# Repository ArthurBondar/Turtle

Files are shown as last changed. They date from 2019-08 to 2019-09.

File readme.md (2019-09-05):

# Underwater Camera Project
Underwater Point of View Camera is designed for marine data collection applications. The primary goal of this project is to aid fisheries and biologist with underwater video collection.

## Features:
* 300m dept rated enclosure
* HD (1080p 30fps) video recording
* GPS location tracking
* 3-5 days battery run time ( 8hr recording per day )
* Ability to interface with various sensors

### Underwater Camera
This unit is designed to use as Point-of-view camera tag for Leatherback turtle studies. The unit features a GPS and a small power-efficient computer. The collected is stored on a microSD card.

### Line Camera
This unit is designed for stationary monitoring application used by fisheries. GPS module is optional for this system. The collected data is stored on a USB flash drive.

### Software Tools
Windows Programs for working with the unit:
* FFMPEG YAG - software for converting cameras native h264 video format to mp4
* Win32 Disk Imager - program for reading and writiing software to the unit

### System Images
Software packages are avaiable on Google Drive:
* Underwater / Line Camera Software Image: https://drive.google.com/file/d/10pP7cINGF-45ElwvxjcI6ze0uSWwasvH/view?usp=sharing

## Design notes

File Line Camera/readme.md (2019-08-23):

## Line Camera
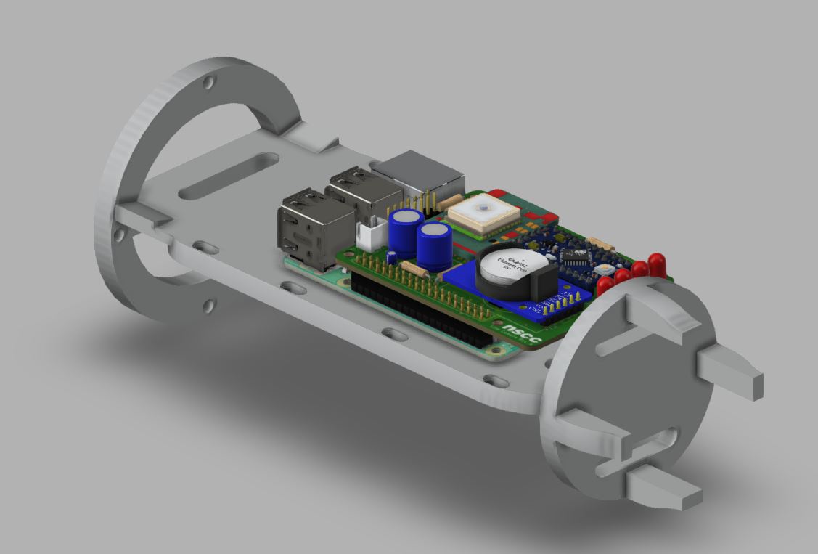
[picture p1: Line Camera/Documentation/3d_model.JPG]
cover photo


### Overview
Line Camera is designed for marine data collection. This device is used in stationary monitoring applications. Camera Tag’s video lapse characteristics can set by the user. The main interface for the system is a removable USB-flash drive. The on-board computer reads the drive during boot and stores all recorded data on it. During long deployments, more than one day, the Tag is designed to enter sleep mode to extend battery life.

### Operation
During deployment, the Tags computer records video during daytime. The main computer shuts down for night-time operation to extend battery life. Recording cycles are handled by a separate microcontroller. Video files, GPS readings, and log file are stored on a removable USB flash drive.

### Main components
* Raspberry Pi + PiCamera 1080p30
* Arduino ProMini (Atmega328)
* Battery Bank + Charger/Boost
* Custom 3D printed parts
* Custom made PCB

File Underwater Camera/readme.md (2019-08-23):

## Underwater Camera
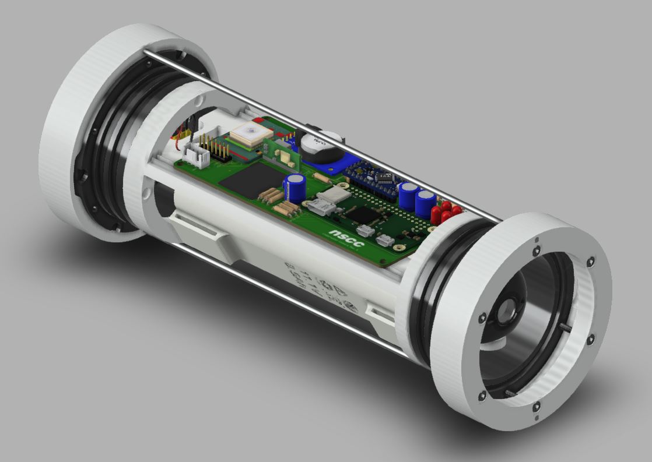
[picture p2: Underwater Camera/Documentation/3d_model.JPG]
cover photo


### Overview
Underwater Camera Tag is designed for marine data collection. This device can be used as
a POV tag for aquatic turtles. The main interface for the system is a removable USB-flash drive. The on-board computer reads the drive during boot and stores all recorded data on it. During long deployments, more than one day, the Tag is designed to enter sleep mode to extend battery life.

### Operation
During deployment, the Tags computer records video and GPS location at daytime. The main computer shuts down for night-time operation to extend battery life. Recording cycles are handled by a separate microcontroller. Video files, GPS readings, and log file are stored on a removable USB flash drive.

### Main components
* Raspberry Pi + PiCamera 1080p30
* Arduino ProMini (Atmega328)
* Battery Bank + Charger/Boost
* Custom 3D printed parts
* Custom made PCB

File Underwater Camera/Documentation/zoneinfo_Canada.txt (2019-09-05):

Atlantic
Central
Eastern
Mountain
Newfoundland
Pacific
Saskatchewan
Yukon

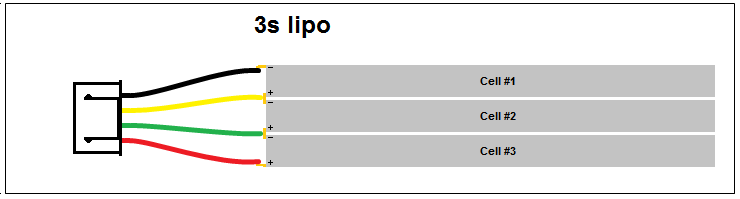
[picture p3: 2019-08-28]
Underwater Camera/Documentation/diagram-3s_lipo.png

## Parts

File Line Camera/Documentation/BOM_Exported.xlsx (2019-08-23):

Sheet: By Part
Qty | Value | Device | Parts | Description
1 | 0.1uF | CAP_THCAP-TH-2MM | C1 | Capacitor Electro. TH
1 | 10k | RES_THRES-D8.5 | R2 | Resistor TH
1 | 30k | RES_THRES-D8.5 | R1 | Resistor TH
4 | 330 | RES_THRES-D8.5 | R3, R4, R5, R6 | Resistor TH
2 | 47uF | CAP_THCAP-ELECTRO-5.08 | C2, C3 | Capacitor Electro. TH
1 | ADA_GPS | ADA_ULTIMATE_GPS9P_BREAKOUT | U3 | Ultimate GPS from Adafruit - Breakout
1 | DS3231_MODULE | DS3231_MODULE | IC1 | DS3231 RTC Breakout Module
1 | HDR2X7 | HDR2X7HDR2X7 | J2
1 | JST-2P | HDR1X22P2.54MM | J1 | Header 2pin 2.54mm pitch
4 | LED_THLED-2.54 | LED_THLED-2.54 | D1, D2, D3, D4 | TH LED - large
1 | PRO_MINI | PRO_MINI | U1 | Arduino Pro Mini from SparkFun 3.3V
1 | RPIPI_3B+ | RPIPI_3B+ | U2 | Pi Header with different package variations

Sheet: By Ref. Des.
Ref. Des. | Value | Device | Description
C1 | 0.1uF | CAP_THCAP-TH-2MM | Capacitor Electro. TH
C2 | 47uF | CAP_THCAP-ELECTRO-5.08 | Capacitor Electro. TH
C3 | 47uF | CAP_THCAP-ELECTRO-5.08 | Capacitor Electro. TH
D1 | LED_THLED-2.54 | LED_THLED-2.54 | TH LED - large
D2 | LED_THLED-2.54 | LED_THLED-2.54 | TH LED - large
D3 | LED_THLED-2.54 | LED_THLED-2.54 | TH LED - large
D4 | LED_THLED-2.54 | LED_THLED-2.54 | TH LED - large
IC1 | DS3231_MODULE | DS3231_MODULE | DS3231 RTC Breakout Module
J1 | JST-2P | HDR1X22P2.54MM | Header 2pin 2.54mm pitch
J2 | HDR2X7 | HDR2X7HDR2X7
R1 | 30k | RES_THRES-D8.5 | Resistor TH
R2 | 10k | RES_THRES-D8.5 | Resistor TH
R3 | 330 | RES_THRES-D8.5 | Resistor TH
R4 | 330 | RES_THRES-D8.5 | Resistor TH
R5 | 330 | RES_THRES-D8.5 | Resistor TH
R6 | 330 | RES_THRES-D8.5 | Resistor TH
U1 | PRO_MINI | PRO_MINI | Arduino Pro Mini from SparkFun 3.3V
U2 | RPIPI_3B+ | RPIPI_3B+ | Pi Header with different package variations
U3 | ADA_GPS | ADA_ULTIMATE_GPS9P_BREAKOUT | Ultimate GPS from Adafruit - Breakout

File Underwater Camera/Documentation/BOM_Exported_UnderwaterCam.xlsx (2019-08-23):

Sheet: By Part
Qty | Value | Device | Parts | Description
2 | 0.1uF | CAP_THCAP-TH-2MM | C1, C5 | Capacitor Electro. TH
1 | 1.35k | RES_THRES-D8.5 | R3 | Resistor TH
1 | 10k | RES_THRES-D8.5 | R2 | Resistor TH
1 | 30k | RES_THRES-D8.5 | R1 | Resistor TH
6 | 33 | RES_THRES-D8.5 | R8, R9, R10, R11, R12, R13 | Resistor TH
4 | 330 | RES_THRES-D8.5 | R4, R5, R6, R7 | Resistor TH
3 | 47uF | CAP_THCAP-ELECTRO-5.08 | C2, C3, C4 | Capacitor Electro. TH
1 | ADA_GPS | ADA_ULTIMATE_GPS9P_BREAKOUT | U3 | Ultimate GPS from Adafruit - Breakout
1 | DS3231_MODULE | DS3231_MODULE | IC1 | DS3231 RTC Breakout Module
1 | HDR2X7 | HDR2X7HDR2X7 | J2
1 | JST-XH | HDR1X4JST-XH | J1 | HEADER 1x4
4 | LED_THLED-2.54 | LED_THLED-2.54 | D1, D2, D3, D4 | TH LED - large
1 | MICRO_SD | MICRO_SD_SNIFFER | IC3 | SparkFun microSD sniffer - breaks out SDIO interface
1 | MICRO_SD_1BIT | MICRO_SD | IC4 | Sparkfun microSD Breakout - SPI/SDIO 1bit accessible
1 | OKX-T/5-D123 | OKX-T/5-D123DMODEL | IC2 | OKX-T/5-D12 by Murata Inc. - Monolithic DC/DC Converter
1 | PI_ZERO | PI_ZERO | U2 | Pi Zero W
1 | PRO_MINI | PRO_MINI | U1 | Arduino Pro Mini from SparkFun 3.3V

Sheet: By Ref. Des.
Ref. Des. | Value | Device | Description
C1 | 0.1uF | CAP_THCAP-TH-2MM | Capacitor Electro. TH
C2 | 47uF | CAP_THCAP-ELECTRO-5.08 | Capacitor Electro. TH
C3 | 47uF | CAP_THCAP-ELECTRO-5.08 | Capacitor Electro. TH
C4 | 47uF | CAP_THCAP-ELECTRO-5.08 | Capacitor Electro. TH
C5 | 0.1uF | CAP_THCAP-TH-2MM | Capacitor Electro. TH
D1 | LED_THLED-2.54 | LED_THLED-2.54 | TH LED - large
D2 | LED_THLED-2.54 | LED_THLED-2.54 | TH LED - large
D3 | LED_THLED-2.54 | LED_THLED-2.54 | TH LED - large
D4 | LED_THLED-2.54 | LED_THLED-2.54 | TH LED - large
IC1 | DS3231_MODULE | DS3231_MODULE | DS3231 RTC Breakout Module
IC2 | OKX-T/5-D123 | OKX-T/5-D123DMODEL | OKX-T/5-D12 by Murata Inc. - Monolithic DC/DC Converter
IC3 | MICRO_SD | MICRO_SD_SNIFFER | SparkFun microSD sniffer - breaks out SDIO interface
IC4 | MICRO_SD_1BIT | MICRO_SD | Sparkfun microSD Breakout - SPI/SDIO 1bit accessible
J1 | JST-XH | HDR1X4JST-XH | HEADER 1x4
J2 | HDR2X7 | HDR2X7HDR2X7
R1 | 30k | RES_THRES-D8.5 | Resistor TH
R2 | 10k | RES_THRES-D8.5 | Resistor TH
R3 | 1.35k | RES_THRES-D8.5 | Resistor TH
R4 | 330 | RES_THRES-D8.5 | Resistor TH
R5 | 330 | RES_THRES-D8.5 | Resistor TH
R6 | 330 | RES_THRES-D8.5 | Resistor TH
R7 | 330 | RES_THRES-D8.5 | Resistor TH
R8 | 33 | RES_THRES-D8.5 | Resistor TH
R9 | 33 | RES_THRES-D8.5 | Resistor TH
R10 | 33 | RES_THRES-D8.5 | Resistor TH
R11 | 33 | RES_THRES-D8.5 | Resistor TH
R12 | 33 | RES_THRES-D8.5 | Resistor TH
R13 | 33 | RES_THRES-D8.5 | Resistor TH
U1 | PRO_MINI | PRO_MINI | Arduino Pro Mini from SparkFun 3.3V
U2 | PI_ZERO | PI_ZERO | Pi Zero W
U3 | ADA_GPS | ADA_ULTIMATE_GPS9P_BREAKOUT | Ultimate GPS from Adafruit - Breakout

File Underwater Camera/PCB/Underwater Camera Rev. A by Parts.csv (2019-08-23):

Part | Value | Device | Package | Description
C1 | 0.1uF | CAP_THCAP-TH-2MM | CAPPRD254W65D300H300B | Capacitor Electro. TH
C2 | 47uF | CAP_THCAP-ELECTRO-5.08 | CAPPRD508W65D1000H1100B | Capacitor Electro. TH
C3 | 47uF | CAP_THCAP-ELECTRO-5.08 | CAPPRD508W65D1000H1100B | Capacitor Electro. TH
C4 | 47uF | CAP_THCAP-ELECTRO-5.08 | CAPPRD508W65D1000H1100B | Capacitor Electro. TH
C5 | 0.1uF | CAP_THCAP-TH-2MM | CAPPRD254W65D300H300B | Capacitor Electro. TH
D1 | LED_THLED-2.54 | LED_THLED-2.54 | LEDRD254W60D565H860B | TH LED - large
D2 | LED_THLED-2.54 | LED_THLED-2.54 | LEDRD254W60D565H860B | TH LED - large
D3 | LED_THLED-2.54 | LED_THLED-2.54 | LEDRD254W60D565H860B | TH LED - large
D4 | LED_THLED-2.54 | LED_THLED-2.54 | LEDRD254W60D565H860B | TH LED - large
IC1 | DS3231_MODULE | DS3231_MODULE | DS3231_MODULE | DS3231 RTC Breakout Module
IC2 | OKX-T/5-D123 | OKX-T/5-D123DMODEL | OKX-T/5-D12 | OKX-T/5-D12 by Murata Inc. - Monolithic DC/DC Converter
IC3 | MICRO_SD | MICRO_SD_SNIFFER | MICRO_SD_SDIO | SparkFun microSD sniffer - breaks out SDIO interface
IC4 | MICRO_SD_1BIT | MICRO_SD | MICRO_SD_SDIO1B | Sparkfun microSD Breakout - SPI/SDIO 1bit accessible
J1 | JST-XH | HDR1X4JST-XH | HDR1X4 | HEADER 1x4
J2 | HDR2X7 | HDR2X7HDR2X7 | HDR2X7
R1 | 30k | RES_THRES-D8.5 | RESAD1176W63L850D250B | Resistor TH
R2 | 10k | RES_THRES-D8.5 | RESAD1176W63L850D250B | Resistor TH
R3 | 1.35k | RES_THRES-D8.5 | RESAD1176W63L850D250B | Resistor TH
R4 | 330 | RES_THRES-D8.5 | RESAD1176W63L850D250B | Resistor TH
R5 | 330 | RES_THRES-D8.5 | RESAD1176W63L850D250B | Resistor TH
R6 | 330 | RES_THRES-D8.5 | RESAD1176W63L850D250B | Resistor TH
R7 | 330 | RES_THRES-D8.5 | RESAD1176W63L850D250B | Resistor TH
R8 | 33 | RES_THRES-D8.5 | RESAD1176W63L850D250B | Resistor TH
R9 | 33 | RES_THRES-D8.5 | RESAD1176W63L850D250B | Resistor TH
R10 | 33 | RES_THRES-D8.5 | RESAD1176W63L850D250B | Resistor TH
R11 | 33 | RES_THRES-D8.5 | RESAD1176W63L850D250B | Resistor TH
R12 | 33 | RES_THRES-D8.5 | RESAD1176W63L850D250B | Resistor TH
R13 | 33 | RES_THRES-D8.5 | RESAD1176W63L850D250B | Resistor TH
U1 | PRO_MINI | PRO_MINI | PRO_MINI | Arduino Pro Mini from SparkFun 3.3V
U2 | PI_ZERO | PI_ZERO | PI_ZERO_W | Pi Zero W
U3 | ADA_GPS | ADA_ULTIMATE_GPS9P_BREAKOUT | ADA_ULTIMATE_GPS | Ultimate GPS from Adafruit - Breakout

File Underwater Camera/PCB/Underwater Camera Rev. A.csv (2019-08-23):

Qty | Value | Device | Package | Parts | Description
2 | 0.1uF | CAP_THCAP-TH-2MM | CAPPRD254W65D300H300B | C1, C5 | Capacitor Electro. TH
1 | 1.35k | RES_THRES-D8.5 | RESAD1176W63L850D250B | R3 | Resistor TH
1 | 10k | RES_THRES-D8.5 | RESAD1176W63L850D250B | R2 | Resistor TH
1 | 30k | RES_THRES-D8.5 | RESAD1176W63L850D250B | R1 | Resistor TH
6 | 33 | RES_THRES-D8.5 | RESAD1176W63L850D250B | R8, R9, R10, R11, R12, R13 | Resistor TH
4 | 330 | RES_THRES-D8.5 | RESAD1176W63L850D250B | R4, R5, R6, R7 | Resistor TH
3 | 47uF | CAP_THCAP-ELECTRO-5.08 | CAPPRD508W65D1000H1100B | C2, C3, C4 | Capacitor Electro. TH
1 | ADA_GPS | ADA_ULTIMATE_GPS9P_BREAKOUT | ADA_ULTIMATE_GPS | U3 | Ultimate GPS from Adafruit - Breakout
1 | DS3231_MODULE | DS3231_MODULE | DS3231_MODULE | IC1 | DS3231 RTC Breakout Module
1 | HDR2X7 | HDR2X7HDR2X7 | HDR2X7 | J2
1 | JST-XH | HDR1X4JST-XH | HDR1X4 | J1 | HEADER 1x4
4 | LED_THLED-2.54 | LED_THLED-2.54 | LEDRD254W60D565H860B | D1, D2, D3, D4 | TH LED - large
1 | MICRO_SD | MICRO_SD_SNIFFER | MICRO_SD_SDIO | IC3 | SparkFun microSD sniffer - breaks out SDIO interface
1 | MICRO_SD_1BIT | MICRO_SD | MICRO_SD_SDIO1B | IC4 | Sparkfun microSD Breakout - SPI/SDIO 1bit accessible
1 | OKX-T/5-D123 | OKX-T/5-D123DMODEL | OKX-T/5-D12 | IC2 | OKX-T/5-D12 by Murata Inc. - Monolithic DC/DC Converter
1 | PI_ZERO | PI_ZERO | PI_ZERO_W | U2 | Pi Zero W
1 | PRO_MINI | PRO_MINI | PRO_MINI | U1 | Arduino Pro Mini from SparkFun 3.3V

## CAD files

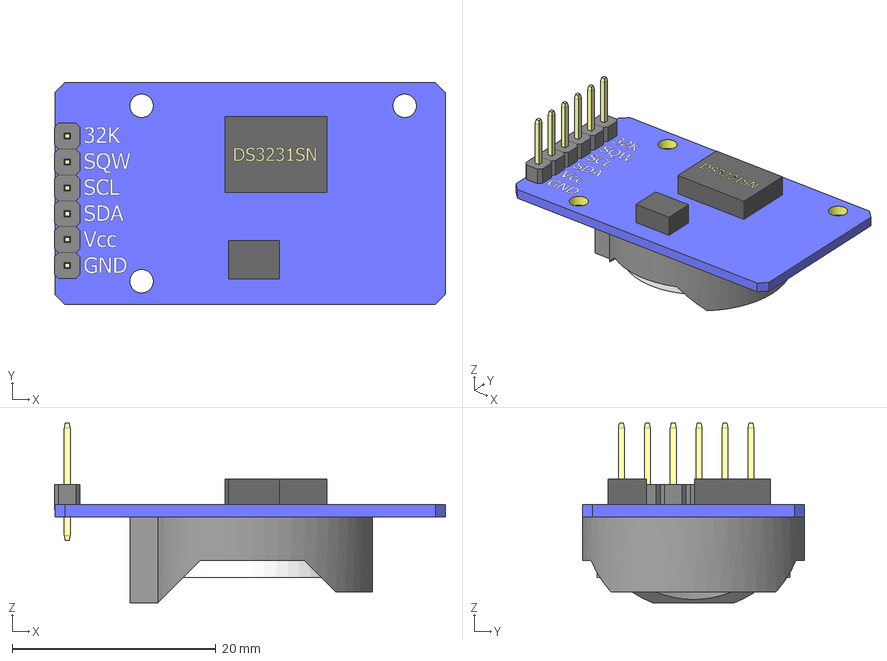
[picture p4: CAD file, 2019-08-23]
Line Camera/PCB/3D Models/DS3231 Timer Assembly.stp
38.3 x 21.8 x 17.6 mm

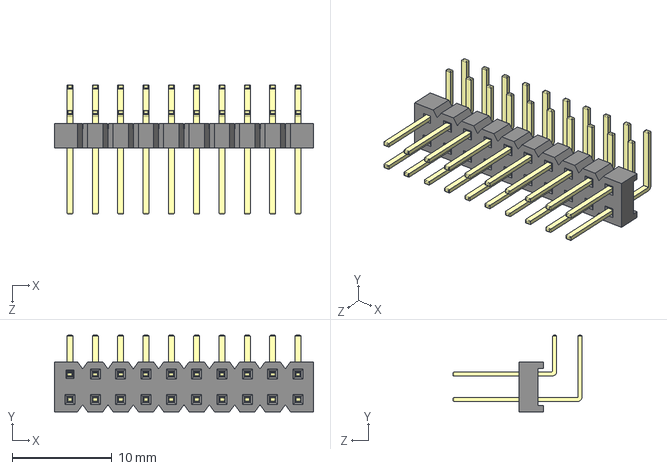
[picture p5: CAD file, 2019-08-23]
Line Camera/PCB/3D Models/20 pin connector_part2.STEP
26.0 x 7.67 x 12.9 mm

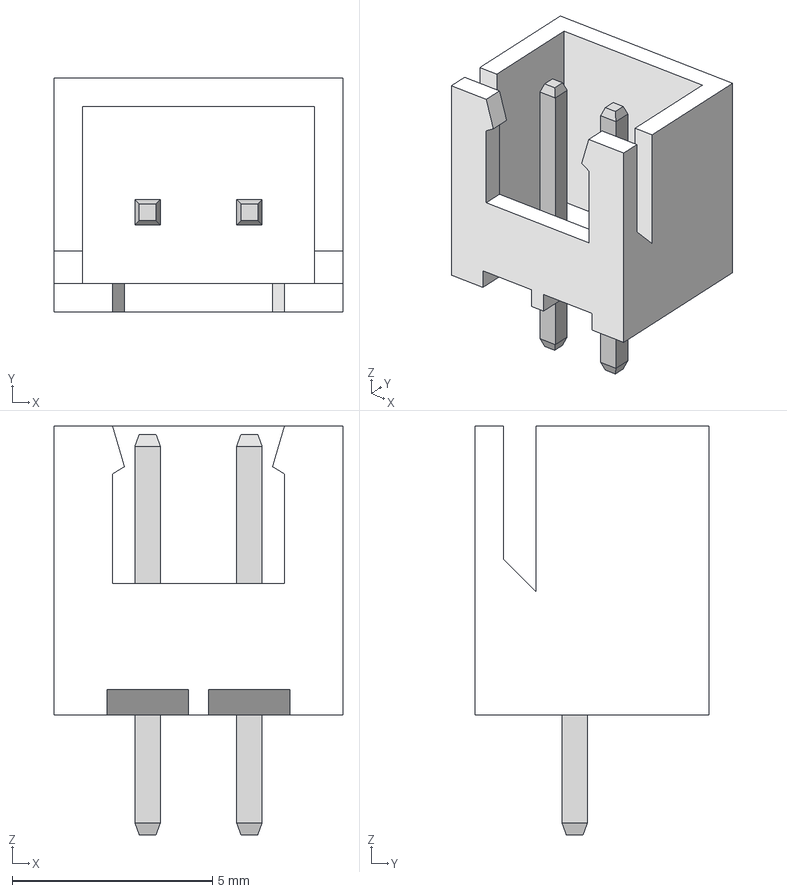
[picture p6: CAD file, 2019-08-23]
Underwater Camera/PCB/3D Models/JST - XH - Thru (V) - 2Pin - 2.54mm.stp
7.21 x 5.84 x 10.2 mm

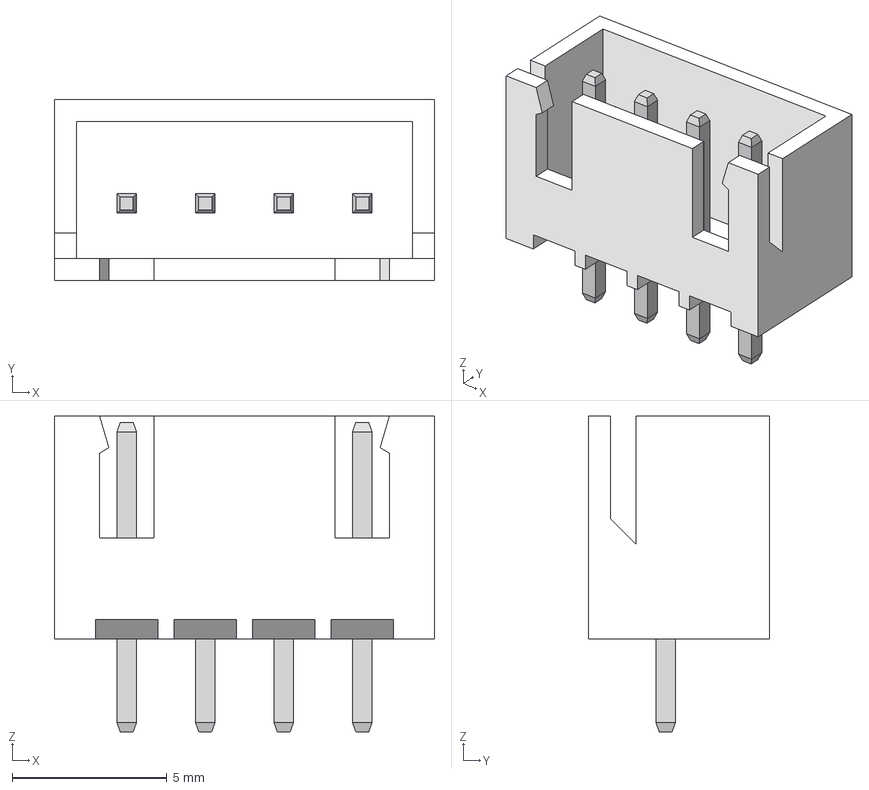
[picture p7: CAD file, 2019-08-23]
Underwater Camera/PCB/3D Models/JST - XH - Thru (V) - 4Pin - 2.54mm.stp
12.3 x 5.84 x 10.2 mm

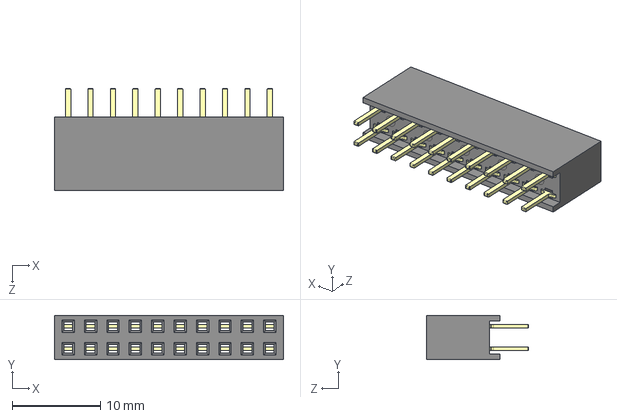
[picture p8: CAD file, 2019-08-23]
Line Camera/PCB/3D Models/20 pin connector.STEP
26.0 x 5.00 x 11.6 mm

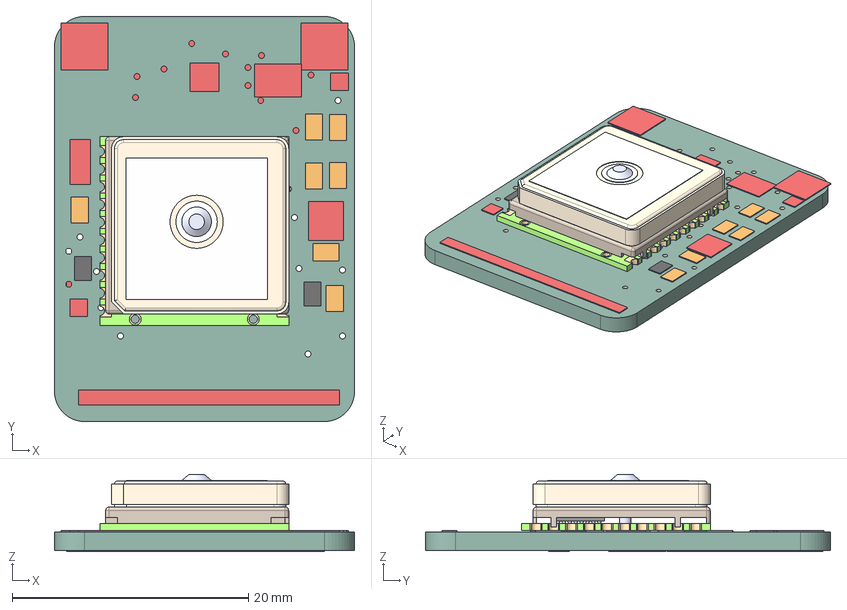
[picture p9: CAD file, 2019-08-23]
Underwater Camera/PCB/3D Models/Adafruit Ultimate GPS.stp
25.4 x 34.3 x 6.52 mm
Board
SOT23-5
CHIPLED_0805
0805-NO x 7
MOUNTINGHOLE_2 x 2
SOD-323 x 2
CR1220
FIDUCIAL_1MM x 2
ADAFRUIT_2
U
1X09_ROUND_70
PCBFEAT-REV-040
ADAFRUIT_5MM
PCB
VFBGA-64
RF Shield
Adhesive Pad
Ceramic Antenna
Rivet

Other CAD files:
Underwater Camera/PCB/3D Models/SparkFun_MicroSD_Sniffer.step
Line Camera/PCB/3D Models/SparkFun_MicroSD_Sniffer.step
Line Camera/PCB/3D Models/SparkFun_MicroSD_Sniffer.blend
Line Camera/PCB/3D Models/SparkFun_MicroSD_Sniffer.stl
Underwater Camera/PCB/3D Models/SparkFun_MicroSD_Sniffer.blend
Underwater Camera/PCB/3D Models/SparkFun_MicroSD_Sniffer.stl

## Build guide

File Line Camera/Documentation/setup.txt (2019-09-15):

# This file is used to set up system configuration
# Edit fields after the equals sign
# Use comments, marked (#), for reference

# Number of recording days left since start of the program
# Use this parameter to limit the number of recording cycles
# If unused, set to a high number > 5
days = 3

# Duration of each video in minutes (default 30)
sections = 30

# Time for the device to turn on in 24hr format [hh:mm]
start = 22:00

# Time for the device to turn off in 24hr format [hh:mm]
end = 06:00

# New datetime and timezone parameers 
# Note: should only be set once after coin cell battery replacement
# Set new system date and time (yes/no)
set date-time = no
# New datetime, format: DD-MM-YYYY T HH:MM:SS
new date-time = 2019-09-09 T 19:06:00
# Set new system timezone (yes/no)
set timezone = no
# Reference - https://en.wikipedia.org/wiki/List_of_tz_database_time_zones
new timezone = America/New_York

# Video recording mode
#	Mode	Resolution	Ratio	FPS		FOV
#	1	1920x1080	16:9	0.1-30fps	Partial
#	2	3280x2464	4:3	0.1-15fps	FulL	(not for video)
#	3	3280x2464	4:3	0.1-15fps	Full	(not for video)
#	4	1640x1232	4:3	0.1-40fps	Full
#	5	1640x922	16:9	0.1-40fps	Full
#	6	1280x720	16:9	40-90fps	Partial
#	7	640x480		4:3	40-90fps	Partial
video mode = 4

# Frames per second (default 25)
# Refer to the table above for acceptible frame rates
# higher rates result in larger fies
fps = 30

# Rotation of the camera module (Default 180) 
# between 0 and 359
rotation = 180

# Enable the use of the GPS module (yes/no)
gps enable = no
# Interval for GPS capture in seconds (Default 50s)
gps interval = 60

# Maximum Video Bitrate in Mbit/sec (Default=10)
# Higher bitrate produce higher quality videos
# Very high rates result in load on the CPU (power consumption)
# and large video files stored on the storage device
#	Bit rate (Mps)	Description			Write Speed	Video Size per Hr
#	25		highest quality, larger files	3.12 MB/s	11.3 GB
#	15		very high quality		1.87 MB/s	6.73 GB
#	10		good quality			1.25 MB/s	4.50 GB
#	5		medium quality (small files)	0.62 MB/s	2.23 GB
bitrate = 10

# Interval for logging processor data to the disk (in minutes)
log interval = 10

# Specify the printed circuit board version ( line camera / underwater camera )
board version = line camera

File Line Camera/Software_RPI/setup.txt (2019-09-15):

# This file is used to set up system configuration
# Edit fields after the equals sign
# Use comments, marked (#), for reference

# Number of recording days left since start of the program
# Use this parameter to limit the number of recording cycles
# If unused, set to a high number > 5
days = 2

# Duration of each video section in minutes (default 30)
sections = 30

# Time for the device to turn on in 24hr format [hh:mm]
start = 08:00

# Time for the device to turn off in 24hr format [hh:mm]
end = 22:00

# New datetime and timezone parameers 
# Note: should only be set once after coin cell battery replacement
# Set new system date and time (yes/no)
# New datetime, format: DD-MM-YYYY T HH:MM:SS
set date-time = no
new date-time = 2019-09-14 T 20:30:00

# Set new system timezone (yes/no)
# Reference - https://en.wikipedia.org/wiki/List_of_tz_database_time_zones
# use America/New_York for USA, MA
set timezone = no
new timezone = America/Halifax

# Video recording mode
#	Mode	Resolution	Ratio	FPS		FOV
#	1	1920x1080	16:9	0.1-30fps	Partial
#	2	3280x2464	4:3	0.1-15fps	FulL	(not for video)
#	3	3280x2464	4:3	0.1-15fps	Full	(not for video)
#	4	1640x1232	4:3	0.1-40fps	Full
#	5	1640x922	16:9	0.1-40fps	Full
#	6	1280x720	16:9	40-90fps	Partial
#	7	640x480		4:3	40-90fps	Partial
video mode = 4

# Frames per second (default 25)
# Refer to the table above for acceptible frame rates
# higher rates result in larger fies
fps = 30

# Rotation of the camera module (Default 180) 
# between 0 and 359
rotation = 0

# Enable the use of the GPS module (yes/no)
gps enable = yes
# Interval for GPS capture in seconds (Default 50s)
gps interval = 60

# Maximum Video Bitrate in Mbit/sec (Default=10)
# Higher bitrate produce higher quality videos
# Very high rates result in load on the CPU (power consumption)
# and large video files stored on the storage device
#	Bit rate (Mps)	Description			Write Speed	Video Size per Hr
#	25		highest quality, larger files	3.12 MB/s	11.3 GB
#	15		very high quality		1.87 MB/s	6.73 GB
#	10		good quality			1.25 MB/s	4.50 GB
#	5		medium quality (small files)	0.62 MB/s	2.23 GB
bitrate = 10

# Interval for logging processor data to the disk (in minutes)
log interval = 15

# Specify the printed circuit board version ( line camera / underwater camera )
board version = underwater camera

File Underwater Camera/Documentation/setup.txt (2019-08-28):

# This file is used to set up system configuration
# Edit fields after the equals sign
# Use comments (#) for reference

# Number of recording days left since start of the program
# Use this parameter to limit the number of recording cycles
# If unused, set to a high number > 5
days = 4

# Duration of each video in minutes (default 30)
sections = 20

# Time for the device to turn on in 24hr format [hh:mm]
start = 15:00

# Time for the device to turn off in 24hr format [hh:mm]
end = 16:30

# New datetime and timezone parameers - should only be set once after coin cell battery replacement
# Set new system date and time (yes/no)
set date-time = no
# New datetime, format - DD-MM-YYYY_HH:MM:SS
new date-time = 18-08-2019_18:45:10
# Set new system timezone (yes/no)
set timezone = no
# Reference - https://en.wikipedia.org/wiki/List_of_tz_database_time_zones
new timezone = America/Halifax

# Video recording mode
#	Mode	Resolution	Ratio	FPS		FOV
#	1	1920x1080	16:9	0.1-30fps	Partial
#	2	3280x2464	4:3	0.1-15fps	FulL	(not for video)
#	3	3280x2464	4:3	0.1-15fps	Full	(not for video)
#	4	1640x1232	4:3	0.1-40fps	Full
#	5	1640x922	16:9	0.1-40fps	Full
#	6	1280x720	16:9	40-90fps	Partial
#	7	640x480		4:3	40-90fps	Partial
video mode = 5

# Frames per second (default 25)
# Refer to the table above for acceptible frame rates
# higher rates result in larger fies
fps = 25

# Rotation of the camera module (Default 180) 
# between 0 and 359
rotation = 180

# Enable the use of the GPS module ( yes / no )
gps enable = no
# Interval for GPS capture in seconds (Default 50s)
gps interval = 60

# Maximum Video Bitrate in Mbit/sec (Default=10)
# Higher bitrate produce higher quality videos
# Very high rates result in load on the CPU (power consumption)
# and large video files stored on the storage device
#	Bit rate (Mps)	Description			Write Speed	Video Size per Hr
#	25		highest quality, larger files	3.12 MB/s	11.3 GB
#	15		very high quality		1.87 MB/s	6.73 GB
#	10		good quality			1.25 MB/s	4.50 GB
#	5		medium quality (small files)	0.62 MB/s	2.23 GB
bitrate = 10

# Interval for logging processor data to the disk (in minutes)
log interval = 5

# Specify the printed circuit board version ( line camera / underwater camera )
board version = line camera

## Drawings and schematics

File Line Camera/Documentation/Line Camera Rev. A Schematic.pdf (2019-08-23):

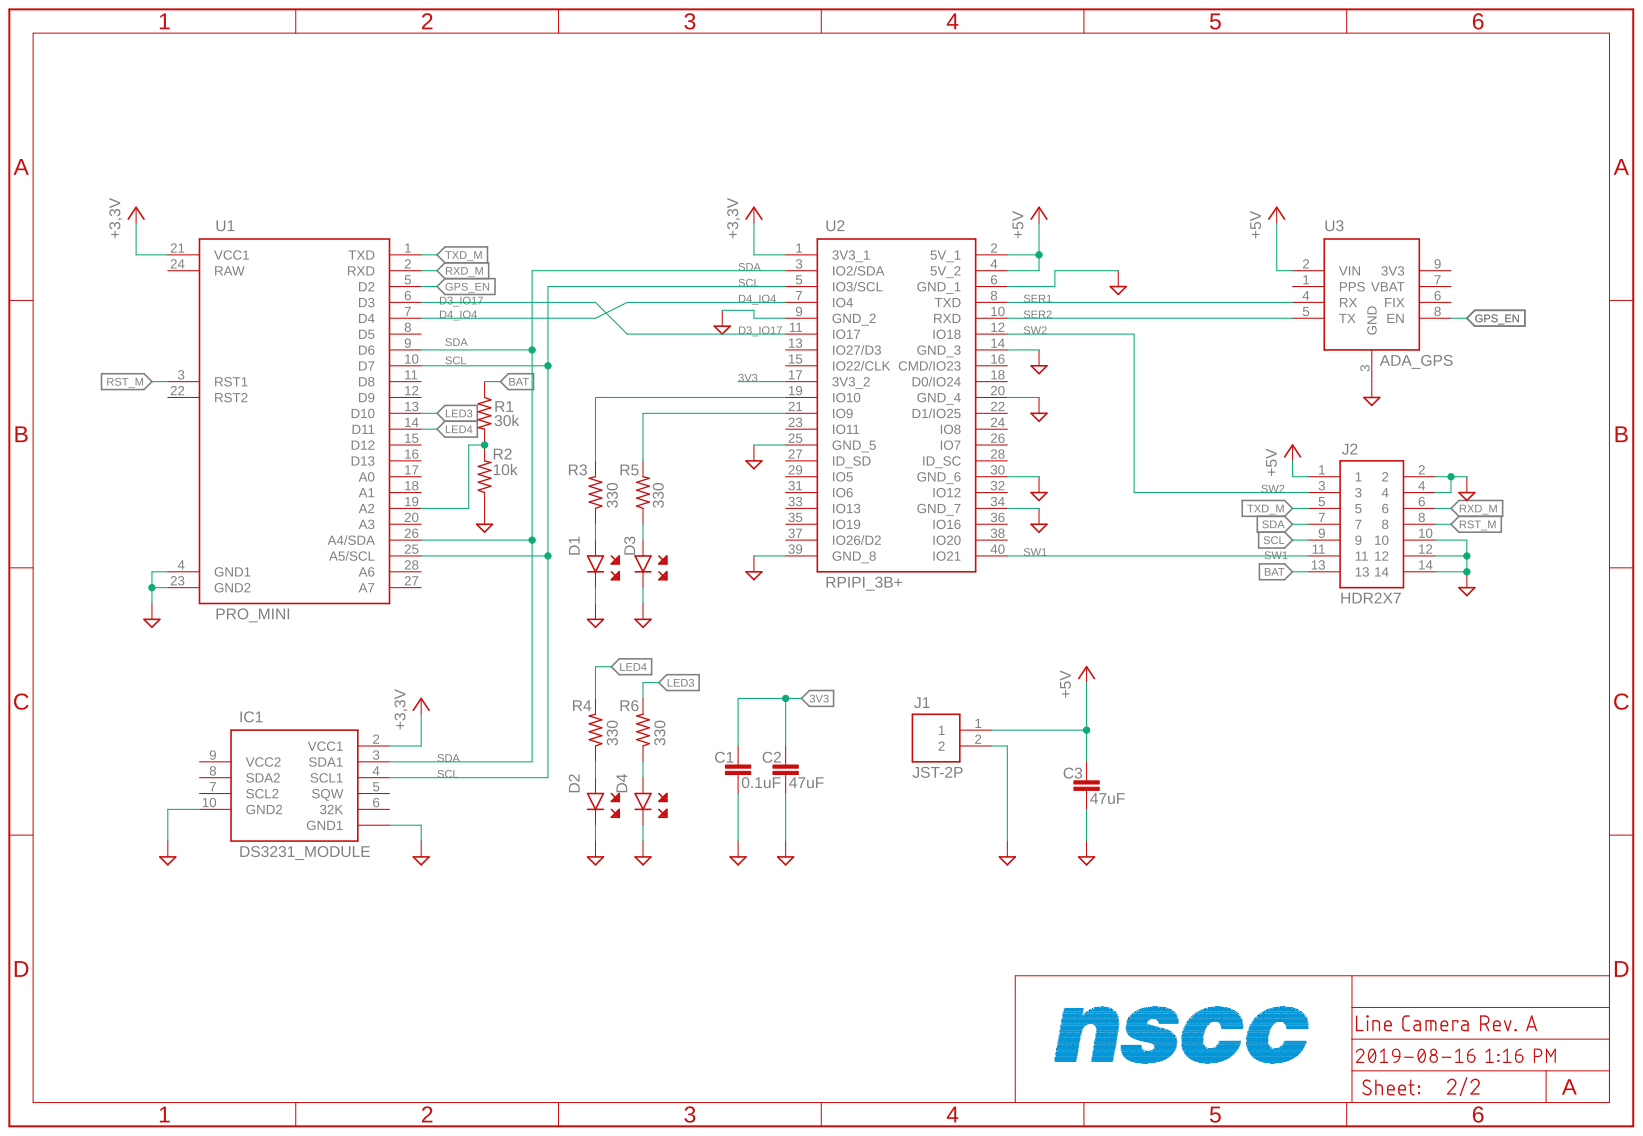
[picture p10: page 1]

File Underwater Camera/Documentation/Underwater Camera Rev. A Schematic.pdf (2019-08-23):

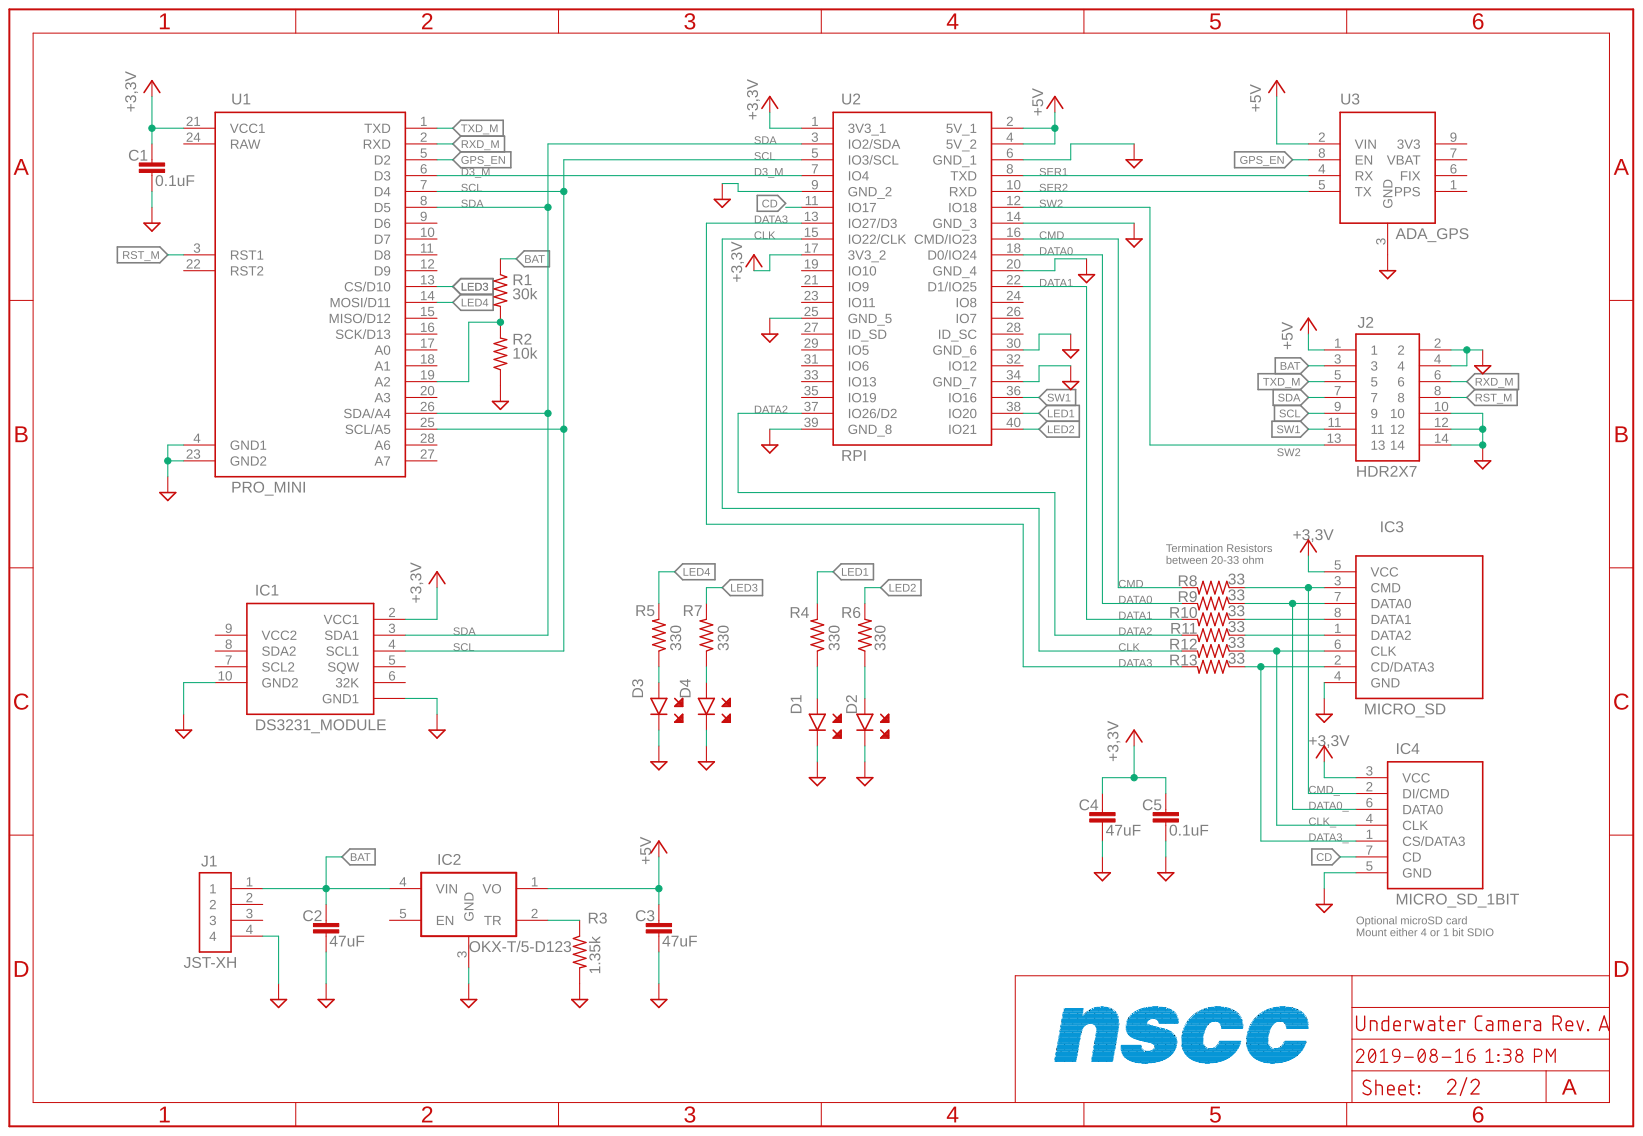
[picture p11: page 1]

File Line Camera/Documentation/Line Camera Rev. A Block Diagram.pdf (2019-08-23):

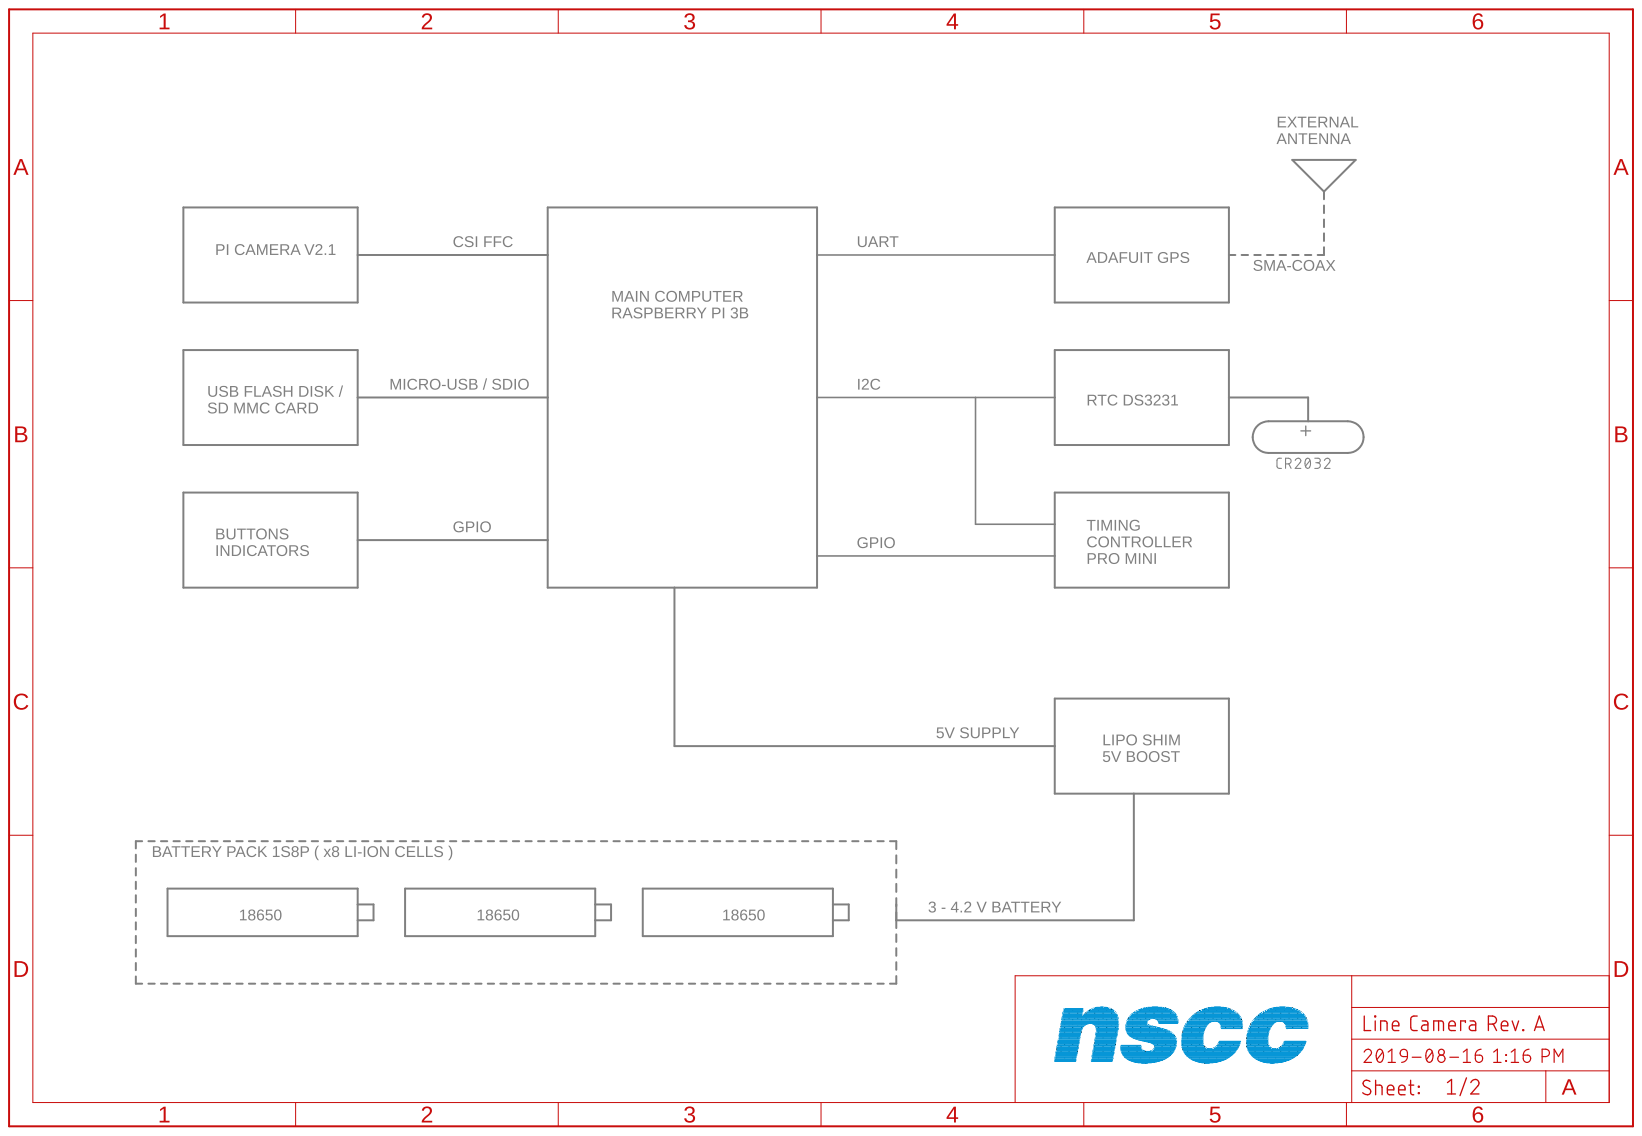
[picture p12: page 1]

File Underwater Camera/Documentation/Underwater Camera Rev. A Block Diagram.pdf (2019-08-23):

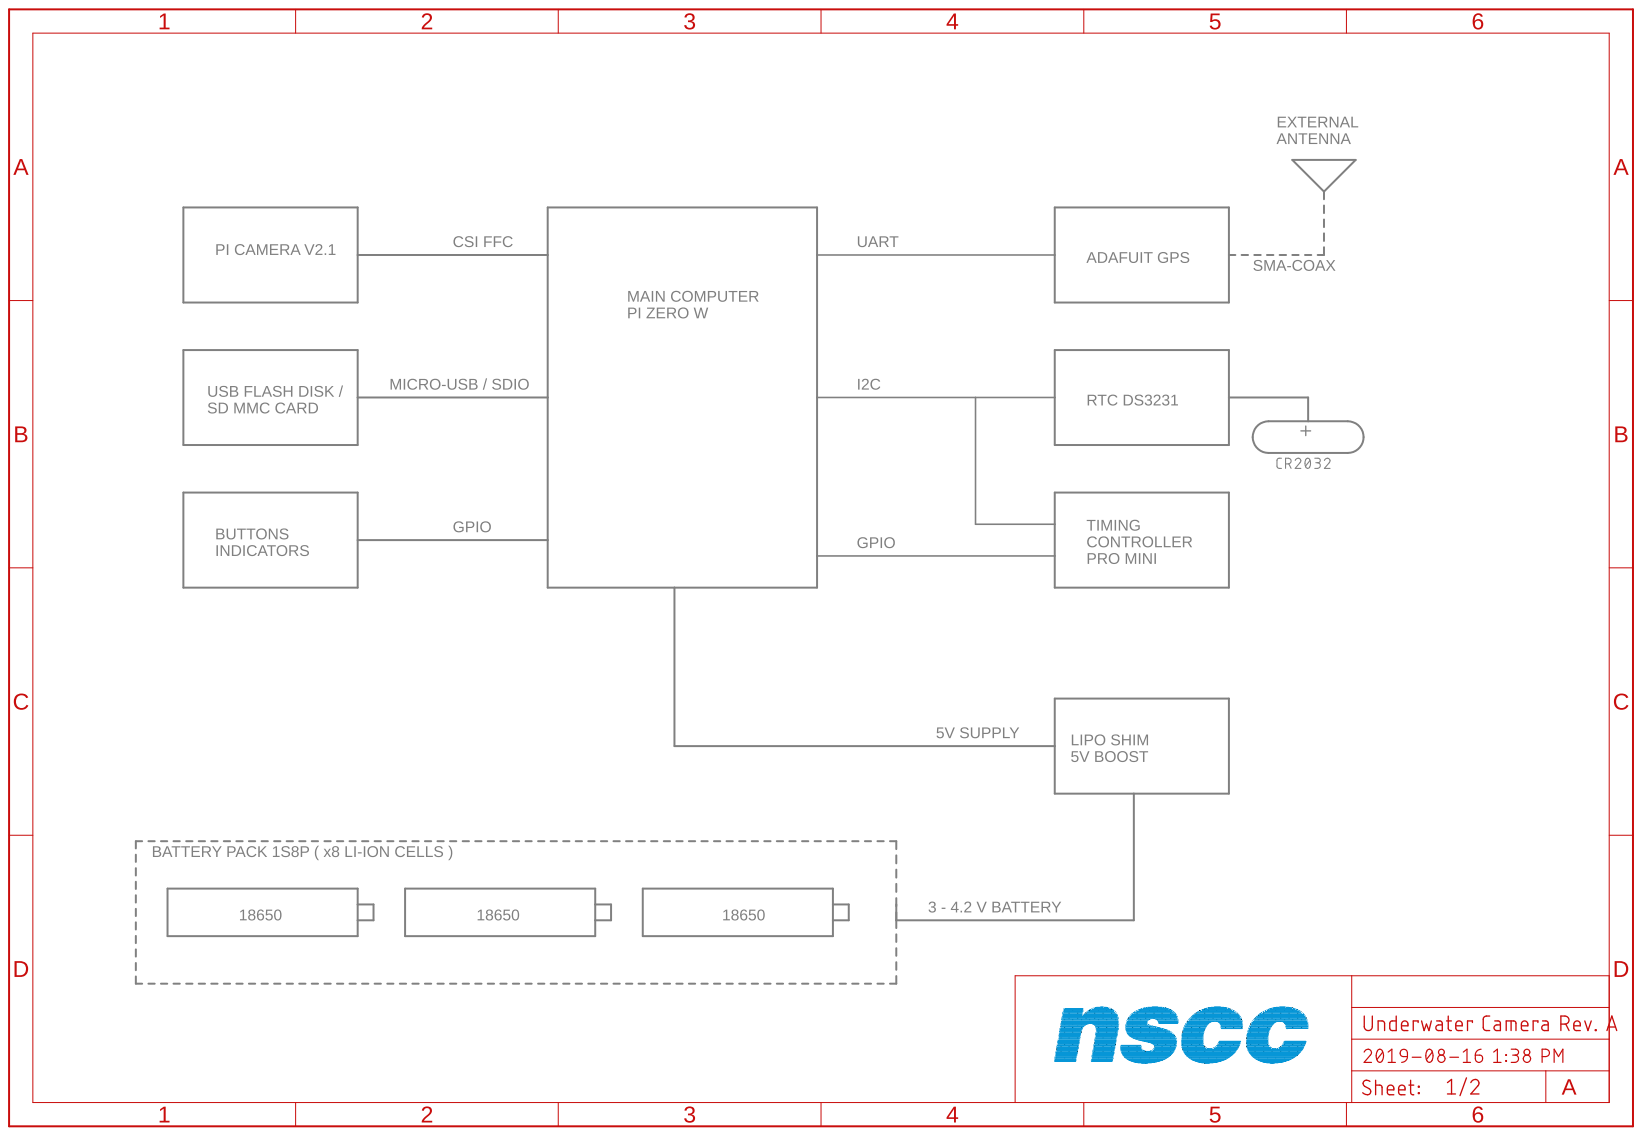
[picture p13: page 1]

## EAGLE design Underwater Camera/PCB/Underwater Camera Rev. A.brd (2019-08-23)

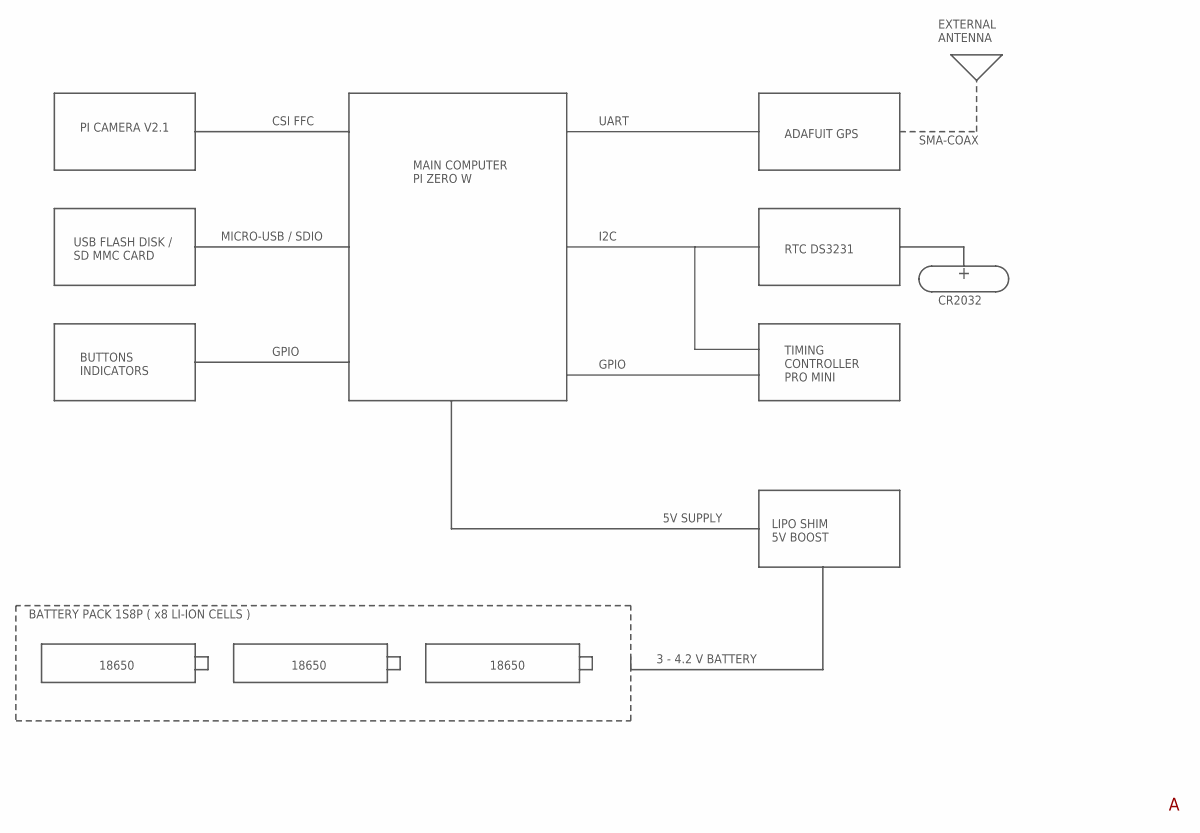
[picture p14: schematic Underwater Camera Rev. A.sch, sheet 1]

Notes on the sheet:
BATTERY PACK 1S8P ( x8 LI-ION CELLS )
LIPO SHIM 5V BOOST
MAIN COMPUTER PI ZERO W
TIMING CONTROLLER PRO MINI
PI CAMERA V2.1
USB FLASH DISK / SD MMC CARD
BUTTONS INDICATORS
ADAFUIT GPS
RTC DS3231
GPIO
5V SUPPLY
3 - 4.2 V BATTERY
SMA-COAX
EXTERNAL ANTENNA
18650
CR2032
MICRO-USB / SDIO
CSI FFC
I2C
UART

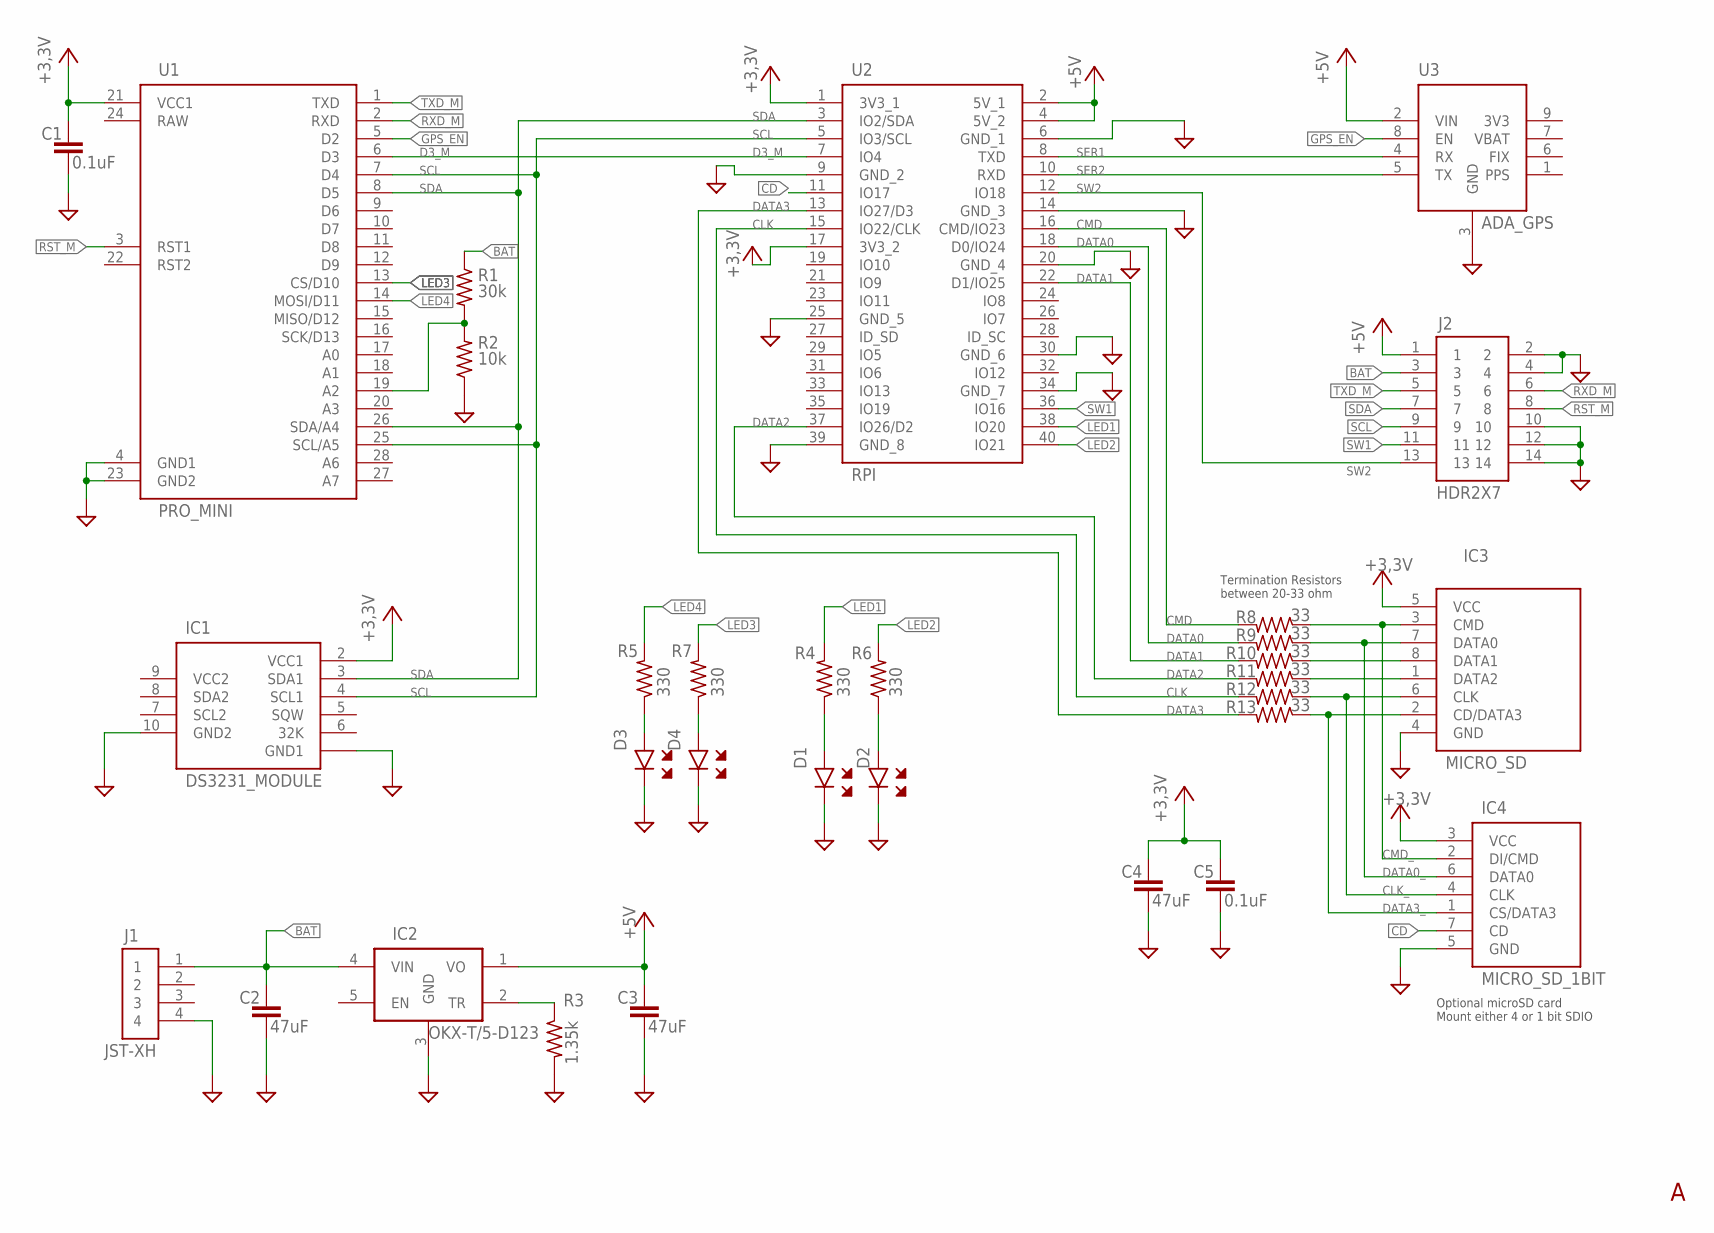
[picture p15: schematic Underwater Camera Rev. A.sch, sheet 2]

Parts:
C1, C5: 0.1uF; CAPPRD254W65D300H300B
C2, C3, C4: 47uF; CAPPRD508W65D1000H1100B
D1, D2, D3, D4: LED_THLED-2.54; LEDRD254W60D565H860B
IC1: DS3231_MODULE
IC2: OKX-T/5-D123; OKX-T/5-D12
IC3: MICRO_SD; MICRO_SD_SDIO
IC4: MICRO_SD_1BIT; MICRO_SD_SDIO1B
J1: JST-XH; HDR1X4
J2: HDR2X7
R1: 30k; RESAD1176W63L850D250B
R2: 10k; RESAD1176W63L850D250B
R3: 1.35k; RESAD1176W63L850D250B
R4, R5, R6, R7: 330; RESAD1176W63L850D250B
R8, R9, R10, R11, R12, R13: 33; RESAD1176W63L850D250B
U1: PRO_MINI
U2: RPI; PI_ZERO_W
U3: ADA_GPS; ADA_ULTIMATE_GPS

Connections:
+3,3V: C1.1, C4.1, C5.1, IC1.2 (VCC1), IC3.5 (VCC), IC4.3 (VCC), U1.21 (VCC1), U2.1 (3V3_1), U2.17 (3V3_2)
+5V: C3.1, IC2.1 (VO), J2.1, U2.2 (5V_1), U2.4 (5V_2), U3.2 (VIN)
BAT: C2.1, IC2.4 (VIN), J1.1, J2.3, R1.1
BAT_IN: R1.2, R2.2, U1.19 (A2)
CD: IC4.7 (CD), U2.11 (IO17)
CLK: R12.2, U2.15 (IO22/CLK)
CLK_: IC3.6 (CLK), IC4.4 (CLK), R12.1
CMD: R8.2, U2.16 (CMD/IO23)
CMD_: IC3.3 (CMD), IC4.2 (DI/CMD), R8.1
D3_M: U1.6 (D3), U2.7 (IO4)
DATA0: R9.2, U2.18 (D0/IO24)
DATA0_: IC3.7 (DATA0), IC4.6 (DATA0), R9.1
DATA1: R10.2, U2.22 (D1/IO25)
DATA1_: IC3.8 (DATA1), R10.1
DATA2: R11.2, U2.37 (IO26/D2)
DATA2_: IC3.1 (DATA2), R11.1
DATA3: R13.2, U2.13 (IO27/D3)
DATA3_: IC3.2 (CD/DATA3), IC4.1 (CS/DATA3), R13.1
GND: C1.2, C2.2, C3.2, C4.2, C5.2, D1.2, D2.2, D3.2, D4.2, IC1.1 (GND1), IC1.10 (GND2), IC2.3 (GND), IC3.4 (GND), IC4.5 (GND), J1.4, J2.2, J2.4, J2.10, J2.12, J2.14, R2.1, R3.2, U1.4 (GND1), U1.23 (GND2), U2.6 (GND_1), U2.9 (GND_2), U2.14 (GND_3), U2.20 (GND_4), U2.25 (GND_5), U2.30 (GND_6), U2.34 (GND_7), U2.39 (GND_8), U3.3 (GND)
GPS_EN: U1.5 (D2), U3.8 (EN)
LED1: R4.2, U2.38 (IO20)
LED2: R6.2, U2.40 (IO21)
LED3: R7.2, U1.13 (CS/D10)
LED4: R5.2, U1.14 (MOSI/D11)
unnamed: D4.1, R7.1
unnamed: IC2.2 (TR), R3.1
unnamed: D1.1, R4.1
unnamed: D2.1, R6.1
unnamed: D3.1, R5.1
RST_M: J2.8, U1.3 (RST1)
RXD_M: J2.6, U1.2 (RXD)
SCL: IC1.4 (SCL1), J2.9, U1.7 (D4), U1.25 (SCL/A5), U2.5 (IO3/SCL)
SDA: IC1.3 (SDA1), J2.7, U1.8 (D5), U1.26 (SDA/A4), U2.3 (IO2/SDA)
SER1: U2.8 (TXD), U3.4 (RX)
SER2: U2.10 (RXD), U3.5 (TX)
SW1: J2.11, U2.36 (IO16)
SW2: J2.13, U2.12 (IO18)
TXD_M: J2.5, U1.1 (TXD)

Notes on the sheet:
Termination Resistors between 20-33 ohm
Optional microSD card Mount either 4 or 1 bit SDIO

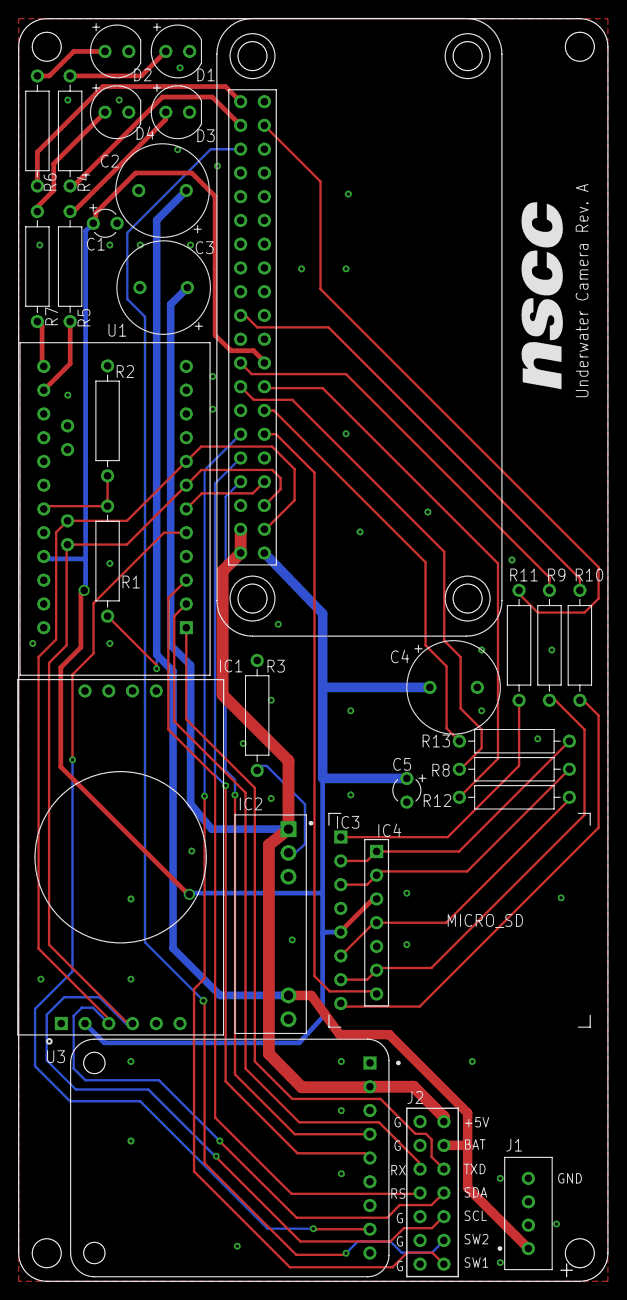
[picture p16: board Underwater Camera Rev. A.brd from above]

Board: 2 copper layers, 63.0 x 135.0 mm, 31 parts (1 on the bottom side), 38 nets.

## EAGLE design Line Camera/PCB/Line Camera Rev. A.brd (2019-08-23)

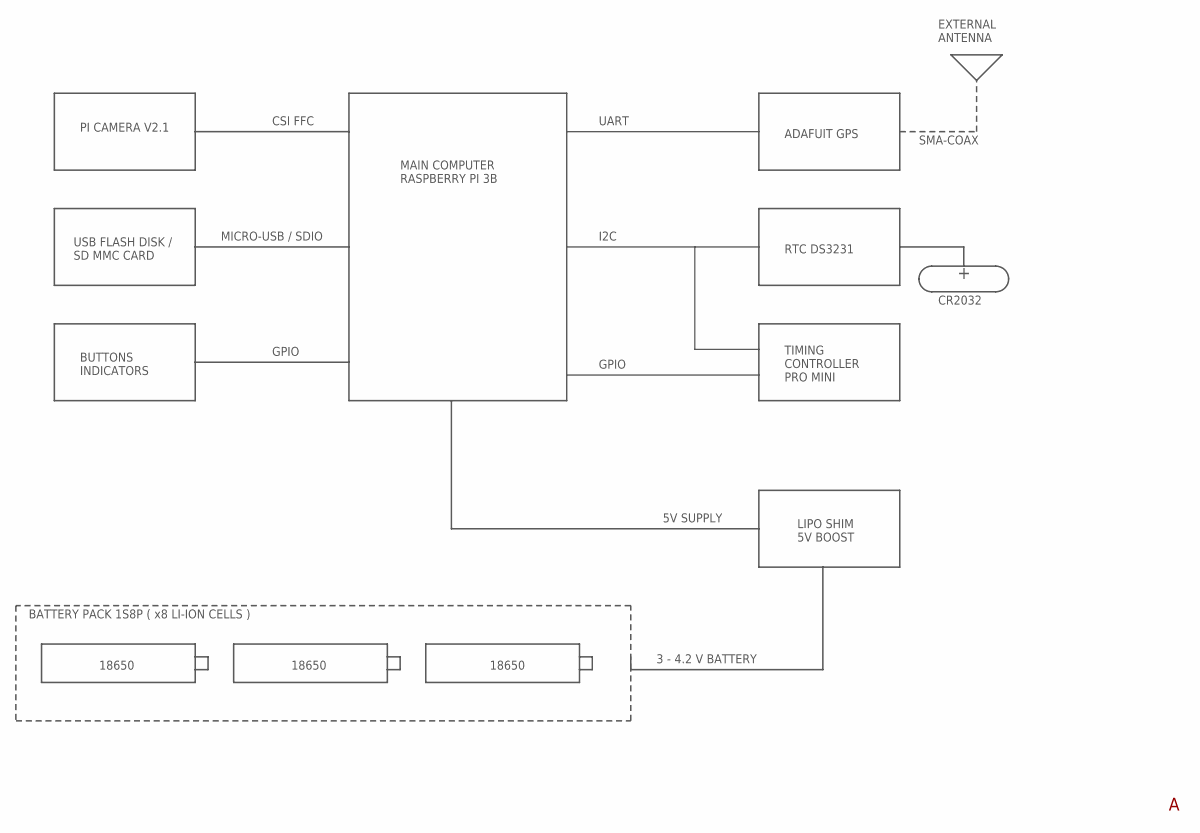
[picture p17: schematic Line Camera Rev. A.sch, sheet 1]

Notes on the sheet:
BATTERY PACK 1S8P ( x8 LI-ION CELLS )
LIPO SHIM 5V BOOST
MAIN COMPUTER RASPBERRY PI 3B
TIMING CONTROLLER PRO MINI
PI CAMERA V2.1
USB FLASH DISK / SD MMC CARD
BUTTONS INDICATORS
ADAFUIT GPS
RTC DS3231
GPIO
5V SUPPLY
3 - 4.2 V BATTERY
SMA-COAX
EXTERNAL ANTENNA
18650
CR2032
MICRO-USB / SDIO
CSI FFC
I2C
UART

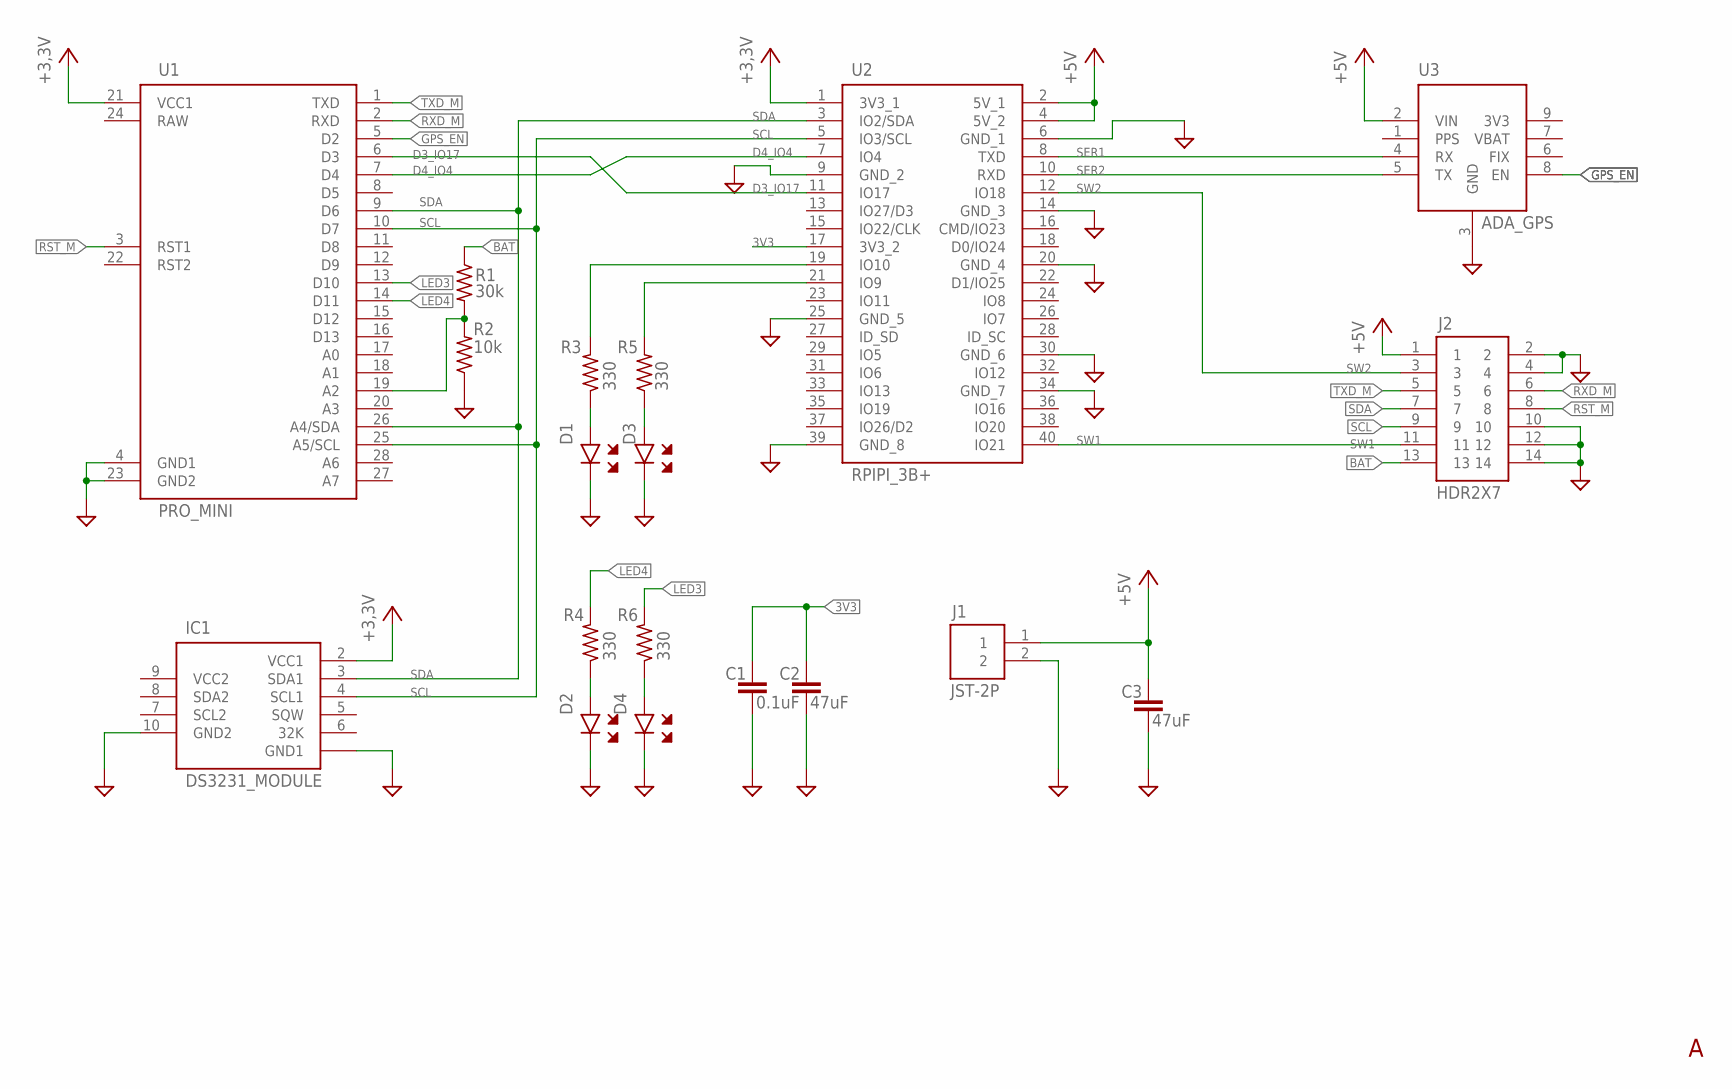
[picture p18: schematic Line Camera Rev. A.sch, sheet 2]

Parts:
C1: 0.1uF; CAPPRD254W65D300H300B
C2, C3: 47uF; CAPPRD508W65D1000H1100B
D1, D2, D3, D4: LED_THLED-2.54; LEDRD254W60D565H860B
IC1: DS3231_MODULE
J1: JST-2P; HDR1X2
J2: HDR2X7
R1: 30k; RESAD1176W63L850D250B
R2: 10k; RESAD1176W63L850D250B
R3, R4, R5, R6: 330; RESAD1176W63L850D250B
U1: PRO_MINI
U2: RPIPI_3B+; PI_3B
U3: ADA_GPS; ADA_ULTIMATE_GPS

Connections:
3V3: C1.1, C2.1, U2.17 (3V3_2)
+3,3V: IC1.2 (VCC1), U1.21 (VCC1), U2.1 (3V3_1)
+5V: C3.1, J1.1, J2.1, U2.2 (5V_1), U2.4 (5V_2), U3.2 (VIN)
BAT: J2.13, R1.1
BAT_IN: R1.2, R2.2, U1.19 (A2)
D3_IO17: U1.6 (D3), U2.11 (IO17)
D4_IO4: U1.7 (D4), U2.7 (IO4)
GND: C1.2, C2.2, C3.2, D1.2, D2.2, D3.2, D4.2, IC1.1 (GND1), IC1.10 (GND2), J1.2, J2.2, J2.4, J2.10, J2.12, J2.14, R2.1, U1.4 (GND1), U1.23 (GND2), U2.6 (GND_1), U2.9 (GND_2), U2.14 (GND_3), U2.20 (GND_4), U2.25 (GND_5), U2.30 (GND_6), U2.34 (GND_7), U2.39 (GND_8), U3.3 (GND)
GPS_EN: U1.5 (D2), U3.8 (EN)
LED1: R3.2, U2.19 (IO10)
LED2: R5.2, U2.21 (IO9)
LED3: R6.2, U1.13 (D10)
LED4: R4.2, U1.14 (D11)
unnamed: D4.1, R6.1
unnamed: D1.1, R3.1
unnamed: D3.1, R5.1
unnamed: D2.1, R4.1
RST_M: J2.8, U1.3 (RST1)
RXD_M: J2.6, U1.2 (RXD)
SCL: IC1.4 (SCL1), J2.9, U1.10 (D7), U1.25 (A5/SCL), U2.5 (IO3/SCL)
SDA: IC1.3 (SDA1), J2.7, U1.9 (D6), U1.26 (A4/SDA), U2.3 (IO2/SDA)
SER1: U2.8 (TXD), U3.4 (RX)
SER2: U2.10 (RXD), U3.5 (TX)
SW1: J2.11, U2.40 (IO21)
SW2: J2.3, U2.12 (IO18)
TXD_M: J2.5, U1.1 (TXD)

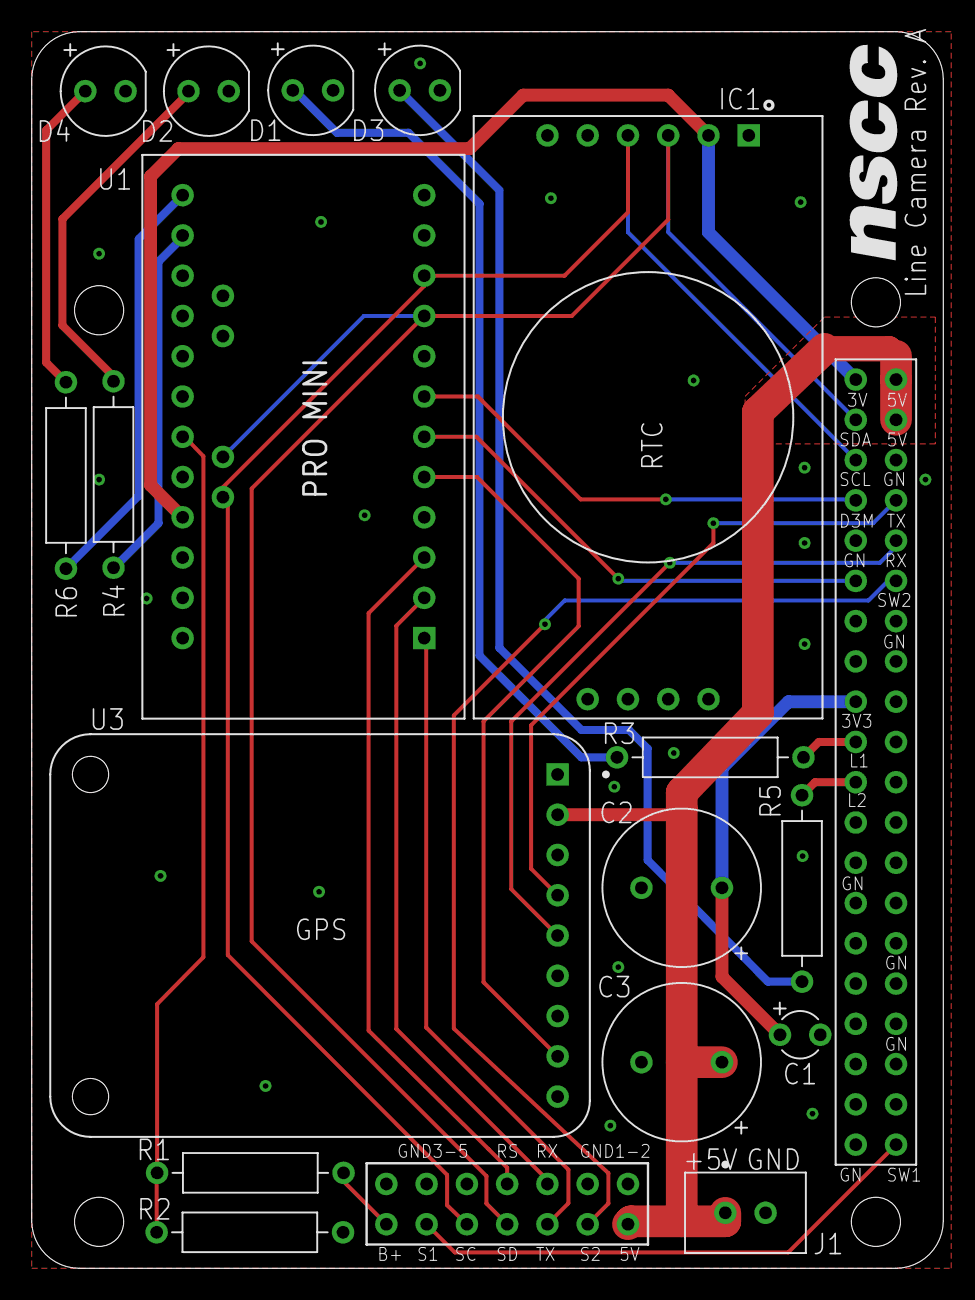
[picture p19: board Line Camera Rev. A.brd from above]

Board: 2 copper layers, 57.5 x 78.0 mm, 19 parts (1 on the bottom side), 26 nets.

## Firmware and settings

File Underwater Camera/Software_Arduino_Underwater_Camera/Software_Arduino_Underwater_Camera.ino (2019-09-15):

/*
   September 9, 2019
   Arthur Bondar

   Board: Line Camera Rev. A

   Timing controller program
   Using I2C protocol to interface with Raspberry Pi
   Start a timer to wake Pi up at the end of set_Sleep cycle
   Triggers PIN 4 on Raspberry Pi to reboot from Half/set_Sleep state

   Excepts commands from the Pi:
   0x01 - Starts set_Sleep timer for the Pi

   I2C message format:
   [Operation code][msg lenght][Hour][Minute]

   I2C status return:
   [SleepMode][BattVoltage MSB][BattVoltage LSB]
*/

#include <Wire.h>           // I2C protocol library

// DEBUG //
// comment or uncomment for serial output
//#define DEBUG

// Digital I/O
#define GPS_EN        2       // D2 - GPS Disable when pulled LOW
#define PI_IO1        3       // D3 - shared with RPI 
#define SDA_P         5       // D6 - connected to I2C SDA line         
#define SCL_P         4       // D6 - connected to I2C SCL line - WAKEUP TRIGGER
#define BATTERY       A2      // Battery Monitor pin
#define LED_1         11      // D10 - connected to LED 1
#define LED_2         10      // D11 - connected to LED 2
#define LED_PCB       13      // D13 - breakout board LED

// ADC parameters
#define ADC_REF       3.3     // use 3.3 for 8MHz arduino
#define ADC_SAMP      5       // Average ADC batt readings
#define ADC_SCALE     4.0    // Resistor divider (1.5k and 4.7k) for the ADC values
#define VOLT_MULT     1000.0  // Multiplier for i2c transmission - illiminates floats
// Timing Interrupt parameters
#define CLOCK_FREQ    8000000 // use 8M for Arduino with 8MHz clock used
#define PRESCALE      256     // Core Clock divider for the timer
#define INT_FREQ      1       // Freq for generated interrupt in Hz
#define COMP_MATCH    ( CLOCK_FREQ / (PRESCALE * INT_FREQ) ) - 1

// I2C Commands
#define I2C_ADDRESS 0x05
#define SLEEP_CODE  0x01
#define CHECK_CODE  0xAA

// Global Variables
// Used to keep track of time, LED state, I2C messages etc.
volatile uint32_t t_Sleep = 0, Sleep = 1, Sec = 0; // Sleep > t_Sleep
volatile bool Sleep_mode = false;
volatile bool New_msg = false;
volatile bool LED_state = false;
volatile bool Sec_INT = false;
volatile bool Message_flag = false;
volatile uint32_t Voltage = 0;

//
//  INIT // -----------------------------
//
void setup()
{
  //  GPIO setup  //
  pinMode(LED_1, OUTPUT);       // LED 1
  pinMode(LED_2, OUTPUT);       // LED 2
  pinMode(LED_PCB, OUTPUT);     // LED on the module

  pinMode(GPS_EN, INPUT);       // Enable/disable the GPS module 5V Line pup10k!
  pinMode(PI_IO1, INPUT);       // Shared IO with RPI
  pinMode(BATTERY, INPUT);      // Shared IO with RPI

  // Initial setup
  digitalWrite(LED_1, LOW);
  digitalWrite(LED_2, LOW);
  digitalWrite(LED_PCB, LOW);

  // Blink LED on the ProMini to start the program properly
  for (uint8_t i = 0; i < 10; i++, _delay(250))
    digitalWrite(LED_PCB, (int) i % 2);

  cli();        //stop all interrupts

  // Set interrupt on Timer1 to run every second
  TCCR1A = 0;                 // set entire TCCR1A register to 0
  TCCR1B = 0;                 // same for TCCR1B
  TCNT1  = 0;                 //initialize counter value to 0
  OCR1A = COMP_MATCH;         // = (8*10^6) / (256*1) - 1 (must be <65536)
  TCCR1B |= (1 << WGM12);     // turn on CTC mode
  TCCR1B |= (1 << CS12);      // Set CS12 bit for 256 prescaler
  TIMSK1 |= (1 << OCIE1A);    // enable timer compare interrupt

  //  I2C setup  //
  Wire.begin(I2C_ADDRESS);      // join i2c bus with address
  Wire.onReceive(receiveEvent); // function pointer to receive event
  Wire.onRequest(sendEvent);    // function pointer for requested I2C register/command

  //digitalWrite(A4, LOW);        // Disable Pullup - RPI has pullups
  //digitalWrite(A5, LOW);

  // Trigger the Pi on reset
  triggerPi(SCL_P);

#ifdef DEBUG //  DEBUG  //
  Serial.begin(115200);           // start serial for debugging
  Serial.println("START");
#endif

  sei();    //allow interrupts
}

//
//  MAIN LOOP  // ---------------------------
//
void loop()
{
  // When message received from i2c
  // Parse the message and reset the flag
  if (New_msg == true) {
    parseMessage(); // Getting data from I2C register
    New_msg = false;
  }

  // Checking for start of set_Sleep mode //
  // Turning ON/OFF the LED on the board to indicate set_Sleep mode
  if (Sleep_mode) {
    digitalWrite(LED_1, HIGH);
    enableGPS(false);
  } else {
    digitalWrite(LED_1, LOW);
    enableGPS(true);
  }

  // Checking for end of set_Sleep mode //
  // If Minutes timer is bigger than set_Sleep time
  // Reset the flag + timer and trigger Pi to wake up
  if (Sleep_mode && (t_Sleep >= Sleep)) {
    Sleep_mode = false;
    t_Sleep = 0;               // Reset sleep timer !
    triggerPi(SCL_P);
#ifdef DEBUG //  DEBUG  //
    Serial.println("Pi Triggered");
#endif
  }

  // Enter if 1 sec past  //
  // Read battery voltage and save in memory
  if (Sec_INT) {
    Sec_INT = false;
    // flick the LED
    digitalWrite(LED_PCB, HIGH);
    _delay(30);
    digitalWrite(LED_PCB, LOW);
    //
    //digitalWrite(LED_PCB, LED_state);
    // Battery voltage reading
    uint16_t adc_avg = 0;
    for (int i = 0; i < ADC_SAMP; i++)
      adc_avg += analogRead(BATTERY);
    adc_avg = (uint16_t) (adc_avg / ADC_SAMP); // Saving battery Voltage
    Voltage = (adc_avg * ADC_REF * ADC_SCALE * VOLT_MULT) / (1024);

#ifdef DEBUG //  DEBUG  //

    Serial.println("tick..");

#endif
  }

  // If seconds timer overflows (every 60 sec)
  // Increment the minutes timer if in sleep mode
  if (Sec >= 60) {
    Sec = 0;                    // seconds overflow
    if (Sleep_mode) t_Sleep ++; // Sleep mode active
    else t_Sleep = 0;
#ifdef DEBUG //  DEBUG  //
    if (Sleep_mode) Serial.println("Sleep: " + String(t_Sleep + 1) + " out of " + String(Sleep));
    Serial.println(" Voltage: " + String( Voltage / VOLT_MULT ) + "v");
#endif
  }

#ifdef DEBUG //  DEBUG  //
  if (Message_flag == true) {
    Message_flag = false;
    byte resp[] = {0, 0, 0, 0, 0};
    resp[0] = (Sleep_mode == true) ? 0x01 : 0x00;             // byte 1 - sleep flag (1/0)
    resp[1] = (byte) ( Voltage & 0x000000FF);        // byte 2 - Voltage LSB
    resp[2] = (byte) ( (Voltage & 0x0000FF00) >> 8); // byte 3 - Votlage B2
    resp[3] = (byte) ( (Voltage & 0x00FF0000) >> 16);// byte 3 - Votlage B3
    resp[4] = (byte) ( (Voltage & 0xFF000000) >> 24);// byte 3 - Votlage MSB
    for (int i = 0; i < 5; i++, Serial.print(", ")) Serial.print(resp[i], HEX);
    Serial.println();
  }
#endif
} // END LOOP

//
//  Interrupt running every seconds to increment the clock (F=1Hz)
//
ISR(TIMER1_COMPA_vect)
{
  Sec++;   // Increment seconds counter
  Sec_INT = true;
}

//
// Interrrupt function, gets triggered when I2C new data available
//
void receiveEvent( void *arg )
{
  New_msg = true;   // sets a flag for the main program
}

//
//  function that receives I2C data and parses it
//  format: [(byte)Operation code][(byte)hours][(byte)minutes]
//
void parseMessage()
{
  byte hour = 0, min = 0, OPC = 0;

  // Reading Operation Code
  if (Wire.available()) OPC = Wire.read();
  else return;
  // Reading Hours
  if (Wire.available()) hour = Wire.read();
  else return;
  // Reading Minutes
  if (Wire.available()) min = Wire.read();
  else return;

  // Power timer command
  if (OPC == SLEEP_CODE)
  {
    // Converting from: hour(24), minute(60) -> minutes
    Sleep = (((uint32_t)hour) * 60) + (uint32_t)min;
    if (Sleep > 1500) { // Error checking
      Sleep = 0;
      return;
    }
    // Setting up mode parameters
    Sec = 0;
    Sleep_mode = true;  // Enter Sleep mode
#ifdef DEBUG //  DEBUG  //
    Serial.println("sleeping for: " + String(Sleep) + " min");
#endif
  }

}

//
//  Enable / Disable GPS - 5V EN line pulled up 10k
//
void enableGPS (bool enable)
{
  if (enable)
    pinMode(GPS_EN, INPUT);     // input tri state mode GPS enabled
  else
  {
    pinMode(GPS_EN, OUTPUT);
    digitalWrite(GPS_EN, LOW);  // Pulled low - GPS disabled
  }
}


//
//  Grounds pin 5 (SCL) on Raspberry pi to wake it up
//
void triggerPi(int pin)
{
  digitalWrite(pin, LOW);   // setting pin LOW
  pinMode(pin, OUTPUT);     // switching port from High-Z to OUTPUT
  _delay(1);
  pinMode(pin, INPUT);      // enabling Tri-state
}

//
//  Interrrupt function, gets triggered when I2C master requests data
//  Sends pack the mode status: [Sleep0/1][VoltageLSB][VoltageMSB]
//
void sendEvent()
{
  byte resp[] = {0, 0, 0, 0, 0};

  resp[0] = (Sleep_mode == true) ? 0x01 : 0x00;             // byte 1 - sleep flag (1/0)
  resp[1] = (byte) ( Voltage & 0x000000FF);        // byte 2 - Voltage LSB
  resp[2] = (byte) ( (Voltage & 0x0000FF00) >> 8); // byte 3 - Votlage B2
  resp[3] = (byte) ( (Voltage & 0x00FF0000) >> 16);// byte 3 - Votlage B3
  resp[4] = (byte) ( (Voltage & 0xFF000000) >> 24);// byte 3 - Votlage MSB
  Wire.write(resp, 5);
  Message_flag = true;
}

// foor loop delay
void _delay(uint32_t ms)
{
  uint32_t start = micros();
  while ( micros() - start < ms * 1000 ) {
    //if (start + ms*1000 < micros() ) start = micros();
    yield();
  }
}

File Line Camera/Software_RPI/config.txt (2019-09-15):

# For more options and information see
# http://rpf.io/configtxt
# Some settings may impact device functionality. See link above for details

# uncomment if you get no picture on HDMI for a default "safe" mode
#hdmi_safe=1

# uncomment this if your display has a black border of unused pixels visible
# and your display can output without overscan
#disable_overscan=1

# uncomment the following to adjust overscan. Use positive numbers if console
# goes off screen, and negative if there is too much border
#overscan_left=16
#overscan_right=16
#overscan_top=16
#overscan_bottom=16

# uncomment to force a console size. By default it will be display's size minus
# overscan.
#framebuffer_width=1280
#framebuffer_height=720

# uncomment if hdmi display is not detected and composite is being output
#hdmi_force_hotplug=1

# uncomment to force a specific HDMI mode (this will force VGA)
#hdmi_group=1
#hdmi_mode=1

# uncomment to force a HDMI mode rather than DVI. This can make audio work in
# DMT (computer monitor) modes
#hdmi_drive=2

# uncomment to increase signal to HDMI, if you have interference, blanking, or
# no display
#config_hdmi_boost=4

# uncomment for composite PAL
#sdtv_mode=2

#uncomment to overclock the arm. 700 MHz is the default.
#arm_freq=800

# Uncomment some or all of these to enable the optional hardware interfaces
dtparam=i2c_arm=on
dtparam=i2s=off
dtparam=spi=off

# Uncomment this to enable the lirc-rpi module
#dtoverlay=lirc-rpi

# Additional overlays and parameters are documented /boot/overlays/README

# Enable audio (loads snd_bcm2835)
#dtparam=audio=on

[pi4]
# Enable DRM VC4 V3D driver on top of the dispmanx display stack
#dtoverlay=vc4-fkms-v3d
#max_framebuffers=2

[all]
#dtoverlay=vc4-fkms-v3d

# Enable miniUART in GPIO pins (OFF) - GPS is on UART1
#enable_uart=1

# Disable Bluetooth to free up ttyAMA0 (PL011) UART for GPIO
dtoverlay=pi3-disable-bt

# Change I2C Speed - more time for Arduino to respond 50k+ too fast
dtparam=i2c1_baudrate=20000

# Enabling SSH over USB (OFF)
# dtoverlay=dwc2

start_x=1

# GPU memory split 16/32/64/128/256
gpu_mem=256

# Enable support for external RTC
dtoverlay=i2c-rtc,ds3231

# Disable WIFI for deployment - uncomment
dtoverlay=pi3-disable-wifi

# Enable SDIO interface for microSD
# Note: Wifi must be disables, since its a shared interface
# Transfer speed = Xclk * 40% = 25MHz * 0.4 = 10MB/s
# Set SDIO interface speed in MHz (internal default is 50MHz)
# add buswidth=1 for 1-bit mode 20Mhz=2.34MB/s
dtoverlay=sdio,sdio_overclock=5

# Pin for GPIO cpu shutdown, tied to SW2
dtoverlay=gpio-shutdown,gpio_pin=18,gpio_pull=up

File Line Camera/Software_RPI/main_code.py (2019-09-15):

#!/usr/bin/python2

'''
    September 7, 2019
    Line Camera Rev. A

    Uses raspberry Pi camera throught raspivid program
    Recording starts and stop at designated times
    Communication with Arduino is impelented with I2C
    Arduino is used a arduino for sleep cycle

    Main program flow:
    - Declare default video recording parameters
    - Parse setup file from USB and overwrite video parameters
    - Get sleep time cycle from setup file
    - Start frist video section
    LOOP:
    - Check for video section to finish
    - Start new section or exit
    END LOOP:
    - Send sleep time to Arduino for wakeup signal
    - Shutdown - enter Halt state
'''

import os, sys, datetime            # essentials
from time import sleep              # sleep function in seconds
from arduino_class import Arduino   # custom made class for i2c com
from parser_class import SetupFile  # custom made class to read setup file
from led_class import Gpio_class    # custom made class to switch led's
from log_class import LogClass      # custom made class to log program status
from timer_class import Timer       # custom class to make timing events
from gps_class import GPS_class     # custom gps class
import subprocess                   # for subprocess opening

# Declaration of default parameters
SOFTWARE_V = "Sep 9, 2019"
DUR =               480             # video duration in minutes
VIDEO_SECTION =     20              # video sections duration min
USB_FOLDER =        "/home/pi/USB/"
SETUP_FILE =        USB_FOLDER + "setup.txt"
LOG_FILE =          USB_FOLDER + "log.txt"
REC_DAY =           3               # keeps track of the current deployment day
# Global Variables
camera = None                       # camera object
poll = 1                            # check for camera thread execution
REC_FILE = ""                       # video section file name variable
led_state = False                   # boolean value to toggle PCB LED
gps_enable = 0                      # boolean value the gps module
DEBUG = False			    # code in debug mode

# Camera default paramters
# array of parameters is passed to raspivid program as cmd args
PARAM = [
    'raspivid',                     # program to call                               (param 0)
    '-t', str(VIDEO_SECTION*60*1000), # videos duration in milliseconds             (param 2)
    '-o', USB_FOLDER+"noname.h264", # output file                                   (param 4)
    '-a', '12',                     # test annotations  20:09:33 10/28/15(param 6)  (param 6)
    '-md', '5',                     # video mode - check table to change            (param 8)
    '-rot', '180',                  # rotation                                      (param 10)
    '-fps', '30',                   # frames per second                             (param 12)
    '-b', '10000000'                # video bit-rate in bits (25M max, 15M good)    (param 14)
    '-n',                           # No Preview
    '-ae', '32,0xff,0x808000',      # Text annotation - Size,TextCol,BackgCol
    '-ih',                          # Add timing to I-frames, needed for software
    '-a', '1024'                    # Text black background
]

# start new camera recording section
# return camera.poll() -> None when running
def start_section(_log, count):
    global camera, REC_FILE
    # assemble filename
    REC_FILE = USB_FOLDER + "s"+str(count)+"_" + datetime.datetime.now().strftime('%Y-%m-%d_%H_%M_%S') + ".h264"
    PARAM[4] = REC_FILE                             # parameter 4 is filename
    # start camera section
    camera = subprocess.Popen(PARAM,stdout = subprocess.PIPE,stderr = subprocess.PIPE)
    sleep(1)
    _log.write("section ["+str(count)+"] started | camera pid: "+str(camera.pid)+" | ret code: "+str(camera.poll())+" | recording ...")
    return camera.poll()

# set Arduino wake up time
# based on sleep parameter in setup file
def set_wakeup(_setup_file, _arduino, _log):
    # get sleep time from setup file and send to Arduino
    s_hr, s_min = _setup_file.getParam("sleep")
    _log.write("setting sleep for "+str(s_hr)+"hr "+str(s_min)+"min")
    # format: (byte)hour, (byte)minute sending data to Arduino using I2C
    if _arduino.setSleep(s_hr, s_min):  _log.write("Arduino sleep set succesfully")
    else:                               _log.write("ERROR: failed setting sleep interval with Arduino ")

# Shutting down routine
# finish recording, shutdown the device
def end_operation(_io, _log):
    global DEBUG
    _io.blink(10)                            # indicate code termination
    if DEBUG == False:
    	_log.write("deployment FINISHED - unmounting usb\r\n")
    	subprocess.call(['umount', USB_FOLDER])
    	subprocess.call(['poweroff'])
        sys.exit()
    else:
	_log.write("FINISHED - debug mode")
	sys.exit()

# Save CPU and IO parameters to the log file
def log_parameters(_io, _log, _arduino):
    global camera
    _io.clear()
    _io.setRun()
    _log.logParam()              	    # log system parameters
    _log.write("Temp "+arduino.getTemperature()+" C")
    _log.write("battery voltage: "+arduino.getVoltage()+" V")
    sleep(2)

# Run Linux Shell Command as a process and log the result - output in log file
def run_cmd (args, cmd_name):
    out = "none"
    try:
        out = subprocess.check_output(args)             # run command and wait for output
        log.write(cmd_name+" finished succesfully")
        return out
    except subprocess.CalledProcessError as e:          # catch non 0 process exit status
        log.write("ERROR: "+cmd_name+" failed | command = "+str(e.cmd)+" | exit code = "+str(e.returncode)+" | output = "+str(e.output)+" | out2 = "+str(out))


# Creating instance of objects
# classes used for: parsing setup file, GPIO controll and I2C commands
log = LogClass(LOG_FILE)                # Log file object
arduino = Arduino()                     # Arduino COM object
setup_file = SetupFile(SETUP_FILE)      # Setup file object
pcb_type = setup_file.getParam("boardversion") # Getting board version string
io = Gpio_class( pcb_type )             # GPIO class (switch,led,alive)
io.clear()                              # turn off al LEDs
led_timer = Timer(0, 0.5)                 # to toggle LEDs
rec_timer = Timer(0, 10)                # checks if recording time is over

# Logging beginning of the program
# indicate beginning of the code with LED flashing
log.space()
log.write("START")
if len(sys.argv) > 1:
	DEBUG = True	# Check if debug mode should be entered
	log.write("Debug Mode entered")
log.write("board type: "+pcb_type+", software: "+SOFTWARE_V)
io.blink(10)
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

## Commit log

2019-07-18 the first commit
    [Adafruit Ultimate GPS.brd, Adafruit Ultimate GPS.sch, Arduino-Pro-Mini.brd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]
2019-08-23 camera software partially tested
    [20 pin connector.STEP, 20 pin connector_part2.STEP, Adafruit Ultimate GPS.brd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]
2019-08-28 adjusted the software to work with both boards
2019-09-05 Line camera software tested
    [config.txt]
2019-09-15 Underwater Camera release 1
    [config.txt]
